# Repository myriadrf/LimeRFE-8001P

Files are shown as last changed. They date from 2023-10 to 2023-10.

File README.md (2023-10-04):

# LimeRFE 8001P

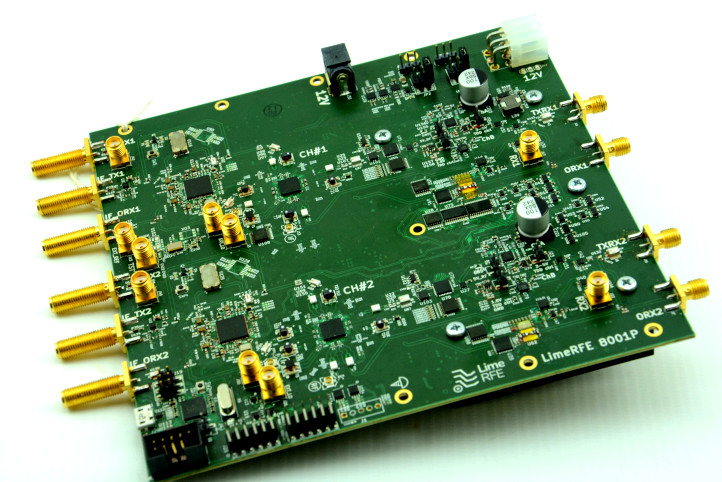
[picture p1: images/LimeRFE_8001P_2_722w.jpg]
LimeRFE 8001P board


## Contents

The LimeRFE 8001P board is a two channel RF front end module capable of frequency
conversion, RF signal amplification and power amplifier linearisation. It can be
configured so that either the integrated driver amplifiers, or external power
amplifiers, are linearised. LimeRFE 8001P is designed with 5G cellular networks
in mind, but may be put to use in other applications with similar requirements.

The directory structure is as follows:

      firmware/<version>/
          LMS8FE                 - Arduino firmware project
      hardware/<version>/
          BOM/                   - Bill of materials
          Gerbers/               - Gerber manufacturing files
          KiCAD/                 - KiCAD design
          PDF/                   - PDF outputs

Note that the firmware should match the hardware version. E.g. use 1v1 firmware
with 1v1 hardware.

## Licensing

The hardware designs are licensed under the Solderpad Hardware License v2.1.

The firmware is licensed under the Apache License, Version 2.0.

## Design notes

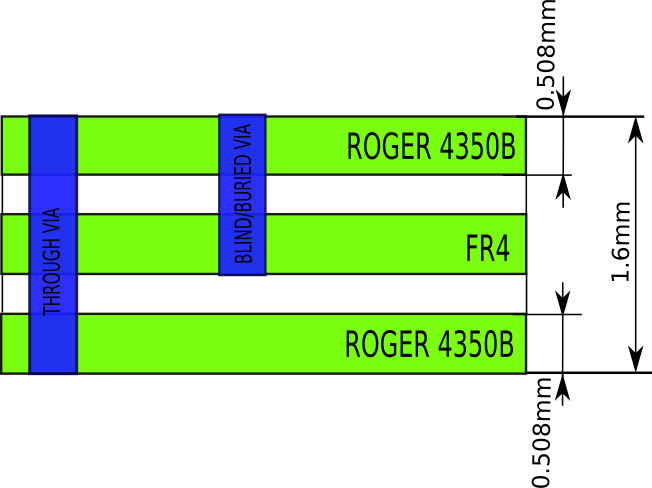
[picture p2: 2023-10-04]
hardware/1v0/Gerbers/STACKUP.png

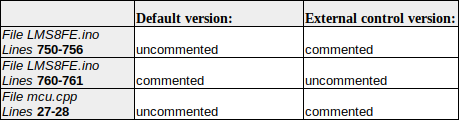
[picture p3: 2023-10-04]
firmware/1v1/TXRX_GUIvsEXTERNAL.png

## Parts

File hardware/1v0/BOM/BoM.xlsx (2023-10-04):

Front_End_5G_1v0
Component | QTY | Reference | Footprint | Supplier | Supplier Part Number | Manufacturer | Manu Part Number | Description | Assemble | Comment | Value
1uF | 48 | C1, C2, C3, C5, C6, C7, C9, C11, C12, C13, C15, C16, C17, C18, C21, C22, C23, C24, C26, C27, C93, C95, C131, C132, C133, C134, C257, C259, C260, C261, C263, C265, C266, C267, C269, C270, C271, C272, C275, C276, C277, C278, C280, C281, C363, C364, C365, C366 | SMD0201 | Digi-Key | 445-8008-1-ND | TDK | C0603X5R0J105M030BC | CAP CER 1UF 6.3V 20% X5R 0201
1nF | 22 | C4, C8, C10, C14, C19, C20, C25, C141, C142, C145, C146, C258, C262, C264, C268, C273, C274, C279, C375, C376, C377, C378 | SMD0201 | Digi-Key | 445-7275-1-ND | TDK Corporation | C0603X7R1E102K030BA | CAP CER 1000PF 25V 10% X7R 0201
10nF | 104 | C28, C29, C30, C31, C32, C34, C37, C40, C42, C48, C50, C83, C91, C92, C98, C167, C169, C179, C180, C181, C182, C183, C184, C189, C205, C223, C224, C225, C226, C229, C230, C231, C235, C242, C246, C251, C252, C253, C254, C255, C256, C284, C285, C287, C288, C289, C290, C296, C307, C321, C322, C323, C324, C325, C326, C327, C329, C330, C387, C388, C389, C390, C391, C392, C393, C396, C458, C459, C466, C467, C468, C525, C526, C575, C576, C577, C578, C579, C580, C581, C583, C584, C585, C586, C587, C588, C589, C590, C591, C592, C593, C594, C595, C596, C597, C598, C599, C600, C601, C603, C605, C630, C631, C634 | SMD0402 | DigiKey | 311-1045-1-ND | Yageo | CC0402ZRY5V7BB103 | CAP_CER_10000PF_16V_Y5V_0402
10uF | 12 | C33, C66, C77, C81, C86, C200, C201, C608, C611, C613, C614, C617 | SMD0603 | Digi-Key | 311-1448-1-ND | Yageo | CC0603MRX5R5BB106 | CAP, CER, 10UF, 6.3V, 20%, X5R, 0603,
NF_10pF | 18 | C35, C399, C400, C403, C404, C405, C409, C410, C518, C519, C531, C532, C534, C537, C538, C539, C573, C574 | SMD0402 | Mouser | 81-GJM1555C1H100GB01 | Murata Electronics | GJM1555C1H100GB01D | Multilayer Ceramic Capacitors MLCC - SMD/SMT 10PF 50V 2% 0402
470pF | 4 | C36, C199, C219, C401 | SMD0402 | Mouser | 81-GRM1555C1H471JA01 | Murata Electronics | GRM1555C1H471JA01D | Multilayer Ceramic Capacitors MLCC - SMD/SMT 0402 470pF 50volts C0G 5%
47nF | 2 | C38, C402 | SMD0402 | Mouser | 81-GCM155R71H473KE2D | Murata Electronics | GCM155R71H473KE02D | Multilayer Ceramic Capacitors MLCC - SMD/SMT 0402 0.047uF 50volts X7R 10%
5pF | 10 | C39, C41, C190, C232, C233, C236, C237, C241, C245, C328 | SMD0402 | Mouser | 80-CBR04C509C5G | KEMET | CBR04C509C5GAC | Multilayer Ceramic Capacitors MLCC - SMD/SMT 50V 5pF C0G 0402 0.25pF
1uF | 30 | C43, C44, C45, C51, C52, C53, C54, C55, C58, C63, C65, C185, C186, C187, C188, C238, C239, C412, C447, C448, C449, C451, C488, C489, C609, C612, C624, C625, C626, C627 | SMD0402 | Digi-Key | 311-1377-1-ND | Yageo | CC0402ZRY5V5BB105 | CAP, CER, 1UF, 6.3V, Y5V, 0402, |  | treba kupiti jos
1nF | 16 | C46, C47, C49, C56, C96, C97, C192, C196, C202, C207, C212, C216, C220, C227, C602, C604 | SMD0402 | DigiKey | 311-1036-1-ND | Yageo | CC0402KRX7R9BB102 | CAP CER 1000PF 50V 10% X7R 0402
10uF | 3 | C57, C78, C206 | SMD1206 | Digi-Key | 311-1376-1-ND | Yageo | CC1206ZKY5V7BB106 | CAP, CER, 10UF, 16V, Y5V, 1206,
1uF | 4 | C59, C82, C610, C616 | SMD0603 | Digi-Key | 490-3897-1-ND | Murata | GRM188R61E105KA12D | CAP_CER_1UF_25V_X5R_0603
4.7uF | 15 | C60, C61, C62, C64, C240, C394, C395, C413, C414, C535, C606, C607, C615, C628, C629 | SMD0402 | DigiKey | 490-5408-1-ND | Murata_Electronics_North_America | GRM155R60J475ME87D | CAP_CER_4.7UF_6.3V_X5R_0402
NF | 22 | C67, C73, C74, C75, C79, C84, C85, C89, C100, C159, C162, C164, C170, C171, C172, C173, C176, C178, C303, C305, C313, C435 | SMD0402 | Mouser | 81-GRM155R71C104KA88 | Murrata Electronic | GRM155R71C104KA88D | SMD/SMT 0402 0.1uF 16volts X7R 10%
1nF | 4 | C68, C163, C166, C174 | SMD0402 | Mouser | 81-GCM155R71H102KA7D | Murrata Electronics | GCM155R71H102KA37D | CAP CER 1000PF 50V 10% X7R 0402
NF_1200pF | 2 | C69, C418 | SMD0402 | Mouser | 81-GRM15R71H122KA01D | Murata_Electronics | GRM155R71H122KA01D | Multilayer_Ceramic_Capacitors_MLCC_-_SMD/SMT_0402_1200pF_50volts_X7R_10%
470nF | 1 | C70 | SMD0402 | Mouser | 81-GRM155R61A474KE5D | Murata_Electronics | GRM155R61A474KE15D | Multilayer_Ceramic_Capacitors_MLCC_-_SMD/SMT
100nF | 2 | C71, C87 | SMD0402 | Mouser | 81-GRM155R71C104KA8J | Murata Electronics | GRM155R71C104KA88J | Multilayer Ceramic Capacitors MLCC - SMD/SMT 0.1uF 16 volts 10%
68nF | 1 | C72 | SMD0402 | Mouser | 81-GRM155R71H683ME4D | Murata_Electronics | GRM155R71H683ME14D | Multilayer_Ceramic_Capacitors_MLCC_-_SMD/SMT
10pF | 1 | C76 | SMD0402 | Farnell | 2332478RL | AVX Corporation | 04023A100JAT2A | CAP, CER, 10PF, 25V, 5%, NPO, 0402,
220pF | 1 | C80 | SMD0402 | DigiKey | 311-1035-2-ND | Yageo | CC0402KRX7R9BB221 | CAP CER, 220PF, 50V, 10%, X7R, 0402,
10uF | 4 | C88, C293, C317, C319 | SMD0603 | Mouser | 81-GRM188R61E106KA3J | Murata Electronics | GRM188R61E106KA73J | Multilayer Ceramic Capacitors MLCC - SMD/SMT
1uF | 1 | C90 | SMD0402 | Mouser | 603-CC402ZRY5V5BB105 | Yageo | CC0402ZRY5V5BB105 | Multilayer Ceramic Capacitors MLCC - SMD/SMT 1.0uF 6.3V Y5V -20/+80%
10pF | 6 | C94, C101, C102, C286, C294, C295 | SMD0201 | Digi-Key | 445-1769-1-ND | TDK Corporation | C0603C0G1H100D030BA | CAP_CER_10PF_50V_C0G_0201
18nF | 1 | C99 | SMD0402 | DigiKey | 311-1706-1-ND | Yageo | CC0402KRX7R7BB183 | CAP_CER_0.018UF_16V_X7R_0402
10pF | 27 | C103, C104, C135, C136, C137, C138, C139, C140, C143, C144, C147, C148, C149, C150, C331, C367, C368, C369, C370, C371, C372, C373, C374, C383, C384, C385, C386 | SMD0201 | Mouser | 81-GJM0335C1E100JB1D | Murata Electronics | GJM0335C1E100JB01D | Multilayer Ceramic Capacitors MLCC - SMD/SMT 10PF 25V 5% 0201
2.3pF | 11 | C105, C106, C119, C120, C123, C124, C332, C333, C334, C347, C348 | SMD0201 | Mouser | 81-GJM0335C1E2R3BB1D | Murata Electronics | GJM0335C1E2R3BB01D | Multilayer Ceramic Capacitors MLCC - SMD/SMT 2.3PF 25V 0.1pf 0201
C_NF | 30 | C107, C108, C109, C110, C111, C112, C115, C116, C128, C130, C151, C153, C154, C157, C158, C335, C337, C338, C339, C340, C356, C357, C358, C359, C360, C361, C362, C380, C381, C382 | SMD0201
0.9pF | 10 | C113, C114, C117, C118, C341, C342, C343, C344, C345, C346 | SMD0201 | Mouser | 81-GJM0335C1ER90BB1D | Murata Electronics | GJM0335C1ER90BB01D | Multilayer Ceramic Capacitors MLCC - SMD/SMT 0.9PF 25V 0.1pf 0201
0.5pF | 10 | C121, C122, C125, C126, C349, C350, C351, C352, C353, C354 | SMD0201 | Mouser | 81-GJM0335C1ER50BB01 | Murata Electronics | GJM0335C1ER50BB01D | Multilayer Ceramic Capacitors MLCC - SMD/SMT 0.5PF 25V 0.1pf 0201
0.6pF | 3 | C127, C129, C355 | SMD0201 | Mouser | 81-GJM0335C1ER60BB1D | Murata Electronics | GJM0335C1ER60BB01D | Multilayer Ceramic Capacitors MLCC - SMD/SMT .6PF 25V .1PF 0201
C_NF | 2 | C152, C336 | SMD0201
1.9nH | 3 | C155, C156, C379 | SMD0201 | Mouser | 81-LQP03TN1N9B02D | Murata Electronics | LQP03TN1N9B02D | Fixed Inductors 1.9 NH +-.1NH
10uF | 1 | C160 | SMD0603_gap04 | Digi-Key | 490-7201-2-ND | Murrata Electronics | GRM188R61C106MA73D | CAP, CER, 10UF, 6.3V, 20%, X5R, 0603,
0.4pF | 2 | C161, C292 | SMD0201 | Digi-Key | 490-8074-1-ND | Murata_Electronics | GJM0335C1ER40WB01D | CAP_CER_0.40PF_25V_NP0_0201
10nF | 4 | C165, C168, C175, C177 | SMD0402 | Mouser | 81-GCM155R71E103KA7D | Murata_Electronics | GCM155R71E103KA37D | Multilayer_Ceramic_Capacitors_MLCC_-_SMD/SMT_0.01uF_25Volts_X7R_10%_
5.6pF | 8 | C191, C194, C198, C210, C211, C214, C218, C283 | SMD0402 | Mouser | 581-04023J5R6BBW | AVX | 04023J5R6BBWTR | Silicon RF Capacitors / Thin Film 25V 5.6pF .1pFTol ThinFilm 0402
10nF | 2 | C193, C213 | SMD0603 | Mouser | 80-C0603C103J5RAC | KEMET | C0603C103J5RAC | Multilayer Ceramic Capacitors MLCC - SMD/SMT 50V 0.01uF 0603 X7R 0.05
1uF | 4 | C195, C197, C215, C217 | SMD0603 | Digi-Key | 490-3897-1-ND | Murata | GRM188R61E105KA12D | CAP_CER_1UF_25V_X5R_0603
100uF | 2 | C203, C221 | EEE-FK1J101P | Mouser | 667-EEE-FK1J101P | Panasonic | EEE-FK1J101P | Aluminium Electrolytic Capacitors - SMD 100UF 63V FK SMD |  | samo 3 komada
4.7uF | 2 | C204, C222 | SMD0603 | DigiKey | - | - | - | CAP_CER_4.7UF_?V_0603
2pF | 2 | C208, C234 | SMD0402 | Mouser | 81-GRM1555C2A2R0CA1D | Murata Electronics | GRM1555C2A2R0CA01D | Multilayer Ceramic Capacitors MLCC - SMD/SMT 0402 2pF 100volts C0G +/-0.25pF
0.6pF | 2 | C209, C282 | SMD0402 | Mouser | 81-GRM1555C2AR60BA1D | Murata Electronics | GRM1555C2AR60BA01D | Multilayer Ceramic Capacitors MLCC - SMD/SMT 0402 0.6pF 100volts C0G +/-0.1pF
1uF | 4 | C228, C320, C632, C633 | SMD0402 | Digi-Key | 311-1377-1-ND | Yageo | CC0402ZRY5V5BB105 | CAP, CER, 1UF, 6.3V, Y5V, 0402,
10pF | 2 | C243, C247 | SMD0402 | Digi-Key | 311-1014-1-ND | Yageo | CC0402JRNPO9BN100 | CAP, CER, 10PF, 50V, 5%, NPO, 0402,
100nF | 15 | C244, C248, C471, C472, C474, C475, C476, C477, C478, C479, C480, C483, C484, C486, C487 | SMD0402 | Mouser | 81-GRM155R71C104KA8J | Murata Electronics | GRM155R71C104KA88J | Multilayer Ceramic Capacitors MLCC - SMD/SMT 0.1uF 16 volts 10%
NF_1000pF | 2 | C249, C250 | SMD0402 | Mouser | 81-GCM155R71H102KA7D | Murata Electronics | GCM155R71H102KA37D | Multilayer Ceramic Capacitors MLCC - SMD/SMT 0402 1000pF 50volts X7R 10%
2.2nF | 1 | C291 | SMD0402 | Mouser | 81-GRM155R71E222KA1D | Murata Electronics | GRM155R71E222KA01D | Multilayer Ceramic Capacitors MLCC - SMD/SMT RECOMMENDED ALT 81-GRM033R71E222KA2D
18pF | 4 | C297, C306, C308, C316 | SMD0402 | Mouser | 81-GRM1555C1H180JA1D | Murata Electronics | GRM1555C1H180JA01D | Multilayer Ceramic Capacitors MLCC - SMD/SMT RECOMMENDED ALT 81-GRM0335C1H180JA1D
100pF | 8 | C298, C300, C301, C304, C309, C311, C312, C315 | SMD0402 | Mouser | 81-GRM1555C1H101JA1D | Murata Electronics | GRM1555C1H101JA01D | Multilayer Ceramic Capacitors MLCC - SMD/SMT 0402 100pF 50volts C0G 5%
1uF | 8 | C299, C302, C310, C314, C462, C481, C482, C620 | SMD0402 | Mouser | 603-CC402ZRY5V5BB105 | Yageo | CC0402ZRY5V5BB105 | Multilayer Ceramic Capacitors MLCC - SMD/SMT 1.0uF 6.3V Y5V -20/+80%
47uF | 1 | C318 | SMD2220 | Mouser | CGA9N3X7R1E476M230KB | Murata Electronics | GRM155R61H474KE11D | Multilayer Ceramic Capacitors MLCC - SMD/SMT .47UF 50V 10% 0402
1nF | 34 | C397, C398, C492, C495, C496, C497, C498, C499, C500, C501, C502, C503, C504, C505, C506, C508, C509, C527, C529, C543, C546, C547, C548, C549, C550, C551, C552, C554, C555, C556, C557, C560, C562, C563 | SMD0402 | Mouser | 81-GRM1555C1H102JA1D | Murata | GRM1555C1H102JA01D | Multilayer Ceramic Capacitors MLCC - SMD/SMT 1000PF 50V 5% 0402
NF_1uF | 2 | C406, C528 | SMD0603 | Mouser | 81-GRM39R105K10 | Murata | GRM188R61A105KA61D | Multilayer Ceramic Capacitors MLCC - SMD/SMT PLEASE SEE MURATA'S SUGGESTED ALTERNATE GRM033R61A105ME15D
NF_2.2uF | 2 | C407, C530 | SMD0603 | Mouser | 81-GRM188R71A225KE5J | Murata | GRM188R71A225KE15J | Multilayer Ceramic Capacitors MLCC - SMD/SMT 2.2UF 10V 10% 0603
NF_1nF | 6 | C408, C411, C524, C533, C536, C582 | SMD0402 | Mouser | 81-GRM1555C1H102JA1D | Murata | GRM1555C1H102JA01D | Multilayer Ceramic Capacitors MLCC - SMD/SMT 1000PF 50V 5% 0402
NF_100nF | 14 | C415, C422, C423, C426, C427, C428, C430, C432, C433, C438, C440, C442, C445, C446 | SMD0402 | DigiKey | 311-1047-1-ND | Yageo | CC0402ZRY5V7BB104 | CAP, CER, 0.1UF, 16V, Y5V, 0402,
NF_10nF | 4 | C416, C425, C441, C444 | SMD0402 | DigiKey | 311-1045-1-ND | Yageo | CC0402ZRY5V7BB103 | CAP_CER_10000PF_16V_Y5V_0402
NF_1nF | 4 | C417, C424, C439, C443 | SMD0402 | DigiKey | 311-1036-1-ND | Yageo | CC0402KRX7R9BB102 | CAP CER 1000PF 50V 10% X7R 0402
NF_470nF | 1 | C419 | SMD0402 | Mouser | 81-GRM155R61A474KE5D | Murata_Electronics | GRM155R61A474KE15D | Multilayer_Ceramic_Capacitors_MLCC_-_SMD/SMT
NF_18nF | 1 | C420 | SMD0402 | DigiKey | 311-1706-1-ND | Yageo | CC0402KRX7R7BB183 | CAP_CER_0.018UF_16V_X7R_0402
NF_68nF | 1 | C421 | SMD0402 | Mouser | 81-GRM155R71H683ME4D | Murata_Electronics | GRM155R71H683ME14D | Multilayer_Ceramic_Capacitors_MLCC_-_SMD/SMT
NF_10pF | 1 | C429 | SMD0402 | Digi-Key | 311-1014-1-ND | Yageo | CC0402JRNPO9BN100 | CAP, CER, 10PF, 50V, 5%, NPO, 0402,
NF_220pF | 1 | C431 | SMD0402 | DigiKey | 311-1035-1-ND | Yageo | CC0402KRX7R9BB221 | CAP CER, 220PF, 50V, 10%, X7R, 0402,
NF_10uF | 2 | C434, C437 | SMD0603_v2 | Digi-Key | 311-1448-1-ND | Yageo | CC0603MRX5R5BB106 | CAP, CER, 10UF, 6.3V, 20%, X5R, 0603,
NF_10uF | 1 | C436 | SMD0603_gap04 | Digi-Key | 311-1448-1-ND | Yageo | CC0603MRX5R5BB106 | CAP, CER, 10UF, 6.3V, 20%, X5R, 0603,
15pF | 6 | C450, C490, C512, C540, C541, C567 | SMD0402 | Mouser | 81-GJM1555C1H150JB1D | Murata Electronics | GJM1555C1H150JB01D | Multilayer Ceramic Capacitors MLCC - SMD/SMT 0402 15pF 50Volts C0G 5%
1nF | 2 | C452, C455 | SMD0603 | Mouser | 581-06035C102K | AVX | 06035C102KAT2A | Multilayer Ceramic Capacitors MLCC - SMD/SMT 50V 1nF X7R 0603 10%TOL
NF_100nF | 2 | C453, C456 | SMD0603 | Mouser | 80-C0603C104M5R | KEMET | C0603C104M5RACTU | Multilayer Ceramic Capacitors MLCC - SMD/SMT 50V 0.1uF 0603 X7R 20%
1000pF | 4 | C454, C457, C463, C621 | SMD0402 | Mouser | 81-GCM155R71H102KA7D | Murata Electronics | GCM155R71H102KA37D | Multilayer Ceramic Capacitors MLCC - SMD/SMT 0402 1000pF 50volts X7R 10%
100pF | 6 | C460, C461, C464, C618, C619, C622 | SMD0402 | Mouser | 667-ECJ-0EC1H101J | Murata Electronics | ECJ-0EC1H101J | Multilayer Ceramic Capacitors MLCC - SMD/SMT 100PF 50V 5% 0402
27pF | 4 | C465, C469, C470, C623 | SMD0402 | Mouser | 81-GCM1555C1H270FA6D | Murata Electronics | GCM1555C1H270FA16D | Multilayer Ceramic Capacitors MLCC - SMD/SMT 0402 27pF 50volts C0G 1%
3.9nF | 1 | C473 | SMD0402 | Mouser | 581-04025C392JAT2A | AVX | 04025C392JAT2A | Multilayer Ceramic Capacitors MLCC - SMD/SMT 50V 3900pF X7R 0402 5%
10uF | 1 | C485 | SMD0603 | Mouser | 81-GRM188R61E106KA3J | Murata Electronics | GRM188R61E106KA73J | Multilayer Ceramic Capacitors MLCC - SMD/SMT
0.2pF | 2 | C491, C542 | SMD0402 | Mouser | 81-GJM1555C1HR20BB01 | Murata Electronics | GJM1555C1HR20BB01D | Multilayer Ceramic Capacitors MLCC - SMD/SMT .2PF 50V .1PF 0402
0.9pF | 2 | C493, C544 | SMD0402 | Mouser | 81-GJM1555C1HR90BB1D | Murata Electronics | GJM1555C1HR90BB01D | Multilayer Ceramic Capacitors MLCC - SMD/SMT .9PF 50V .1PF 0402
2.2uF | 6 | C494, C510, C513, C545, C564, C568 | SMD0603 | Mouser | 81-GRM188R71A225KE5J | Murata | GRM188R71A225KE15J | Multilayer Ceramic Capacitors MLCC - SMD/SMT 2.2UF 10V 10% 0603
0.5pF | 2 | C507, C561 | SMD0402 | Mouser | 81-GJM1555C1HR50BB01 | Murata Electronics | GJM1555C1HR50BB01D | Multilayer Ceramic Capacitors MLCC - SMD/SMT .5PF 50V .1PF 0402
NF_47nF | 6 | C511, C514, C515, C553, C558, C559 | SMD0402 | Mouser | 81-GCM155R71H473KE2D | Murata Electronics | GCM155R71H473KE02D | Multilayer Ceramic Capacitors MLCC - SMD/SMT 0402 0.047uF 50volts X7R 10%
10pF | 4 | C516, C517, C571, C572 | SMD0402 | Mouser | 81-GJM1555C1H100GB01 | Murata Electronics | GJM1555C1H100GB01D | Multilayer Ceramic Capacitors MLCC - SMD/SMT 10PF 50V 2% 0402
NF_100nF | 4 | C520, C521, C565, C566 | SMD0402 | Mouser | 81-GRM155R71C104KA8J | Murata Electronics | GRM155R71C104KA88J | Multilayer Ceramic Capacitors MLCC - SMD/SMT 0.1uF 16 volts 10%
NF_100pF | 4 | C522, C523, C569, C570 | SMD0402 | Mouser | 81-GRM1555C1H101JA1D | Murata Electronics | GRM1555C1H101JA01D | Multilayer Ceramic Capacitors MLCC - SMD/SMT 0402 100pF 50volts C0G 5%
47346-0001 | 1 | CON1 | USB-MINI-B | Mouser | 538-47346-0001 | Manufacturer | 47346-0001 | MICRO USB B RECPT BTTM MOUNT ASSY
SML-D12M1WT86 | 4 | D1, D2, D3, D4 | LED_0603 | Mouser | 755-SML-D12M1WT86 | Rohm Semiconductor | SML-D12M1WT86 | LED YLW/GREEN 2.2V DIFFUSED 0603 SMD
600 Ohm @100MHz | 38 | FB1, FB2, FB3, FB4, FB5, FB6, FB7, FB8, FB9, FB10, FB11, FB12, FB13, FB14, FB15, FB25, FB26, FB27, FB28, FB31, FB32, FB33, FB34, FB35, FB36, FB37, FB38, FB39, FB40, FB41, FB42, FB43, FB44, FB45, FB48, FB49, FB50, FB51 | SMD0201 | Digi-Key | 587-3277-1-ND | Taiyo Yuden | BK0603TS601-T | FERRITE BEAD 600 OHM 0201
600_Ohm_@_100MHz_2A | 1 | FB16 | SMD0805 | Mouser | 810-MPZ2012S601AT000 | TDK | MPZ2012S601AT000 | Ferrite Beads 600ohms 2A 100mOhms 0805 Ferrite Chip
60 Ohm @100MHz, 1A | 15 | FB17, FB18, FB19, FB20, FB21, FB23, FB24, FB30, FB46, FB53, FB54, FB55, FB56, FB57, FB58 | SMD0805 | Digi-Key | 445-2204-1-ND | TDK Corporation | MMZ2012Y600B | FERRITE CHIP, BEAD, 60 OHM, SMD,
600 Ohm @ 100MHz, 0.3A | 1 | FB22 | SMD0402 | Digi-Key | 445-2162-1-ND | TDK Corporation | MMZ1005S601C | FERRITE CHIP BEAD, 600 OHM, SMD,
600_Ohm_@_100MHz_500mA | 1 | FB29 | SMD0603_gap04 | Digi-Key | 490-3994-2-ND | Murata_Electronics | BLM18EG601SN1D | FERRITE_BEAD_600_OHM_0603_1LN_
NF_600 Ohm @ 100MHz, 0.3A | 1 | FB47 | SMD0402 | Digi-Key | 445-2162-1-ND | TDK Corporation | MMZ1005S601C | FERRITE CHIP BEAD, 600 OHM, SMD,
NF_600_Ohm_@_100MHz_500mA | 1 | FB52 | SMD0603_gap04 | Digi-Key | 490-3994-2-ND | Murata_Electronics | BLM18EG601SN1D | FERRITE_BEAD_600_OHM_0603_1LN_
AD5513 | 2 | IC1, IC2 | AD5513 | Mouser | 584-ADL5513ACPZ-R7 | Analog Devices | ADL5513ACPZ-R7 | RF Detector 1MHz-4GHz 80 dB
732511352 | 2 | J1, J29 | SMA_vert_SMD | Digi-Key | WM9458-ND | Molex Inc | 732511352 | SMA JACK 50 OHM VERT SMD
68000-103HLF | 3 | J2, J24, J27 | pin_header_1x3 | Digi-Key | 609-3461-ND | FCI | 68000-103HLF | BERGSTIK II .100" SR STRAIGHT
732511352 | 6 | J3, J13, J14, J17, J22, J26 | SMA_vert_SMD | Digi-Key | WM9458-ND | Molex Inc | 732511352 | SMA JACK 50 OHM VERT SMD
SMA_H_142-0701-851 | 10 | J4, J5, J6, J7, J8, J9, J10, J11, J15, J20 | SMA_H | Mouser | 530-142-0701-851 | Johnson / Cinch Connectivity Solutions | 142-0701-851 | RF Connectors / Coaxial Connectors PC END MT JCK GLD .062 BOARDS TAB
Jumper_SNM-100-BK-T | 5 | J12, J25, J47, J54, J56 | SNM-100-BK-T | Mouser | 200-SNM100BKT | Samtec | SNM-100-BK-T | Headers & Wire Housings .050" x .100" Shunt
CONN_HEADER_TSM-102-04-T-SV | 9 | J16, J18, J21, J23, J37, J40, J46, J53, J55 | TSM-102-04-T-SV | Mouser | TSM-102-04-T-SV | Samtec | 200-TSM10204TSV | Headers & Wire Housings .100" Surface Mount Terminal Strip
CONN_HEADER_TSM-103-04-F-DV | 1 | J19 | TSM-103-04-F-DV | Mouser | 200-TSM10304FDV | Samtec | TSM-103-04-F-DV | Headers & Wire Housings .100" Surface Mount Terminal Strip
PMOD_CONN | 6 | J28, J30, J31, J36, J51, J52 | PMOD_CONN | Mouser | 649-95278-401-06LF | Amphenol FCI | 95278-401-06LF | Headers & Wire Housings BERGSTIK SMT
10056844-114LF | 2 | J32, J48 | 10056844-114LF | Mouser |  | HARTING |  | Headers & Wire Housings 14 POS VERTICAL THROUGH MNT
NF_UMC_SMD | 2 | J33, J34 | UMC_SMD | Digi-Key | WM5587CT-ND | Molex_LLC | 734120110 | CONN_UMC_RCPT_STR_50_OHM_SMD
UMC_SMD | 2 | J35, J57 | UMC_SMD | Digi-Key | WM5587CT-ND | Molex_LLC | 734120110 | CONN_UMC_RCPT_STR_50_OHM_SMD
732511352 | 4 | J42, J43, J49, J50 | SMA_vert_SMD | Digi-Key | WM9458-ND | Molex Inc | 732511352 | SMA JACK 50 OHM VERT SMD
CONN_HEADER_1744037-2 | 1 | J44 | 1744037-2 | Digikey | TSM-102-04-T-SV | TE Connectivity AMP Connectors | A112698-ND | Connector Header Through Hole 2 position 0.200" (5.08mm)
PIN_HEADER_2X3_0353180620 | 1 | J45 | 353180620 | Digikey | WM13196-ND | Molex | 353180620 | Connector Header Through Hole, Right Angle 6 position 0.165" (4.20mm)
15912060 | 2 | JP1, JP2 | PINHEADER_2X3 | Digi-Key | WM17449-ND | Molex Inc | 15912060 | CONN HEADER 6POS .100" VERT TIN
 | 3 | L1, L3, L27 | SMD0201
1.6nH | 5 | L2, L4, L28, L29, L30 | SMD0201 | Mouser | 81-LQP03TN1N6B02D | Murata | LQP03TN1N6B02D | Fixed Inductors 56nH 5% Hi-Freq
8.2nH | 4 | L5, L7, L9, L11 | IND_0402 | Mouser | 81-LQW15AN8N2G00D | Murata | LQW15AN8N2G00D | Fixed Inductors 8.2 NH 2%
3.6nH | 10 | L6, L8, L10, L12, L32, L33, L34, L36, L37, L38 | IND_0402 | Mouser | 81-LQW15AN3N6C10D | Murata | LQW15AN3N6C10D | Fixed Inductors 3.6 NH 2%
1.2nH | 2 | L13, L18 | SMD0402 | Mouser | 994-0402CS-1N2XJLU | Coilcraft | 0402CS-1N2XJLU | Fixed Inductors 1005 1.2nH Unshld 5% 740mA 90mOhms AECQ2
10nH | 4 | L14, L16, L19, L21 | SMD0603 | Mouser | 994-0603HP-10NXGLW | Coilcraft | 0603HP-10NXGLW | Fixed Inductors 0603HP Hi Perfrmnce 10 nH 2 % 1.4 A
2.4nH | 2 | L15, L20 | SMD0402 | Mouser | 994-0402CS-2N4XGLU | Coilcraft | 0402CS-2N4XGLU | Fixed Inductors 1005 2.4nH Unshld 2% 790mA 68mOhms AECQ2
3.3nH | 2 | L17, L22 | SMD0603 | Mouser | 994-0603HP-3N3XJLW | Coilcraft | 0603HP-3N3XJLW | Fixed Inductors 0603 3.3nH Unshld 5% 1.9A 24mOhms
47nH | 2 | L23, L25 | SMD0402 | Mouser | 81-LQW04AN47NH20D | Murata | LQW04AN47NH20D | Fixed Inductors Fixed IND 47nH 140mA NONAUTO
56nH | 2 | L24, L26 | SMD0402 | Mouser | 81-LQW15AW56NJ80D | Murata | LQW15AW56NJ80D | Fixed Inductors Fixed IND 56nH 480mA NONAUTO
8.2nH | 2 | L31, L35 | IND_0402 | Coilcraft | 0402HP-8N2XJLU | Coilcraft | 0402HP-8N2XJLU | Inductor, 8.2 nH, 0402, 5%,
2.2uH | 1 | L39 | SPM6530T-2R2M | Mouser | 810-SPM6530T-2R2M | TDK Corporation | SPM6530T-2R2M | Fixed Inductors 2.2uH 0.0173ohms 7.1x6.5x3mm
12nH | 2 | L40, L41 | SMD0402 | Mouser | 994-0402CS-12NXJLW | COILCRAFT | 0402CS-12NXJLW | Fixed Inductors 0402CS AEC-Q200 12 nH 5 % 0.64 A
470R | 2 | L42, L65 | SMD0402 | Mouser | 81-BLM15BD471SN1D | Murata | BLM15BD471SN1D | Ferrite Beads 470 OHM 25%
470R | 1 | L43 | SMD0603 | Mouser | 81-BLM18PG471SN1D | Murata | BLM18PG471SN1D | Ferrite Beads 470 OHM 25%
5.6nH | 4 | L44, L45, L66, L67 | SMD0402 | Digikey | 587-1513-2-ND | Taiyo Yuden | HK10055N6S-T | FIXED IND 5.6NH 430MA 230MOHM SM
18nH | 2 | L46, L68 | SMD0402 | Digikey | 587-1522-6-ND | Taiyo Yuden | HK100518NJ-T | 18 nH Unshielded Multilayer Inductor 310 mA 550mOhm Max 0402 (1005 Metric)
68nH | 2 | L47, L48 | SMD0603 | Mouser | 994-0603CS-68NXJLW | Coilcraft | 0603CS-68NXJLW | Fixed Inductors 0603HP Hi Perfrmnce 100 nH 5 % 0.47 A
1.2nH | 4 | L57, L58, L69, L70 | SMD0402 | DigiKey | 587-1499-6-ND | Taiyo Yuden | HK10051N2S-T | 1.2 nH Unshielded Multilayer Inductor 300 mA 90mOhm Max 0402 (1005 Metric)
3.3nH | 2 | L59, L71 | SMD0402 | Digikey | 587-1507-6-ND | Taiyo Yuden | HK10053N3S-T | 3.3 nH Unshielded Multilayer Inductor 550 mA 160mOhm Max 0402 (1005 Metric)
8.2nH | 2 | L60, L72 | SMD0402 | DigiKey | 587-1517-6-ND | Taiyo Yuden | HK10058N2J-T | 8.2 nH Unshielded Multilayer Inductor 380 mA 280mOhm Max 0402 (1005 Metric)
2.2nH | 4 | L61, L62, L73, L74 | SMD0402 | DigiKey | 587-1503-6-ND | Taiyo Yuden | HK10052N2S-T | 2.2 nH Unshielded Multilayer Inductor 700 mA 130mOhm Max 0402 (1005 Metric)
120R | 4 | L63, L64, L75, L76 | SMD0603 | Mouser | 81-BLM11A121S | Murata | BLM18AG121SN1D | Ferrite Beads 120 OHM 25%
Green | 5 | LD1, LD2, LD4, LD5, LD6 | LED_0603 | Digi-Key | 475-1409-1-ND | OSRAM Opto Semiconductors Inc | LG Q971-KN-1 | LED, CHIPLED, 570NM, GREEN, 0603, SMD,
NF_MMBT3904 | 2 | Q1, Q3 | MMBT3904 | Mouser | 637-MMBT3904 | Diotec Semiconductor | MMBT3904 | Bipolar Transistors - BJT Bipolar Transistor, SOT-23, 40V, 200mA, NPN
2N7002-G | 2 | Q2, Q4 | SOT-23 | Mouser | 2N7002-G | onsemi / Fairchild | 2N7002-G | MOSFET N-CHANNEL 60V 115mA
0R | 6 | R1, R91, R92, R130, R160, R161 | SMD0201 | Digi-Key | RHM0.0CCCT-ND | Rohm Semiconductor | MCR006YRTJ000 | RES 0.0 OHM 1/20W JUMP 0201 SMD
10K | 47 | R2, R41, R70, R106, R111, R118, R120, R131, R133, R134, R135, R136, R137, R140, R141, R142, R144, R149, R153, R207, R208, R209, R211, R251, R252, R253, R255, R283, R284, R285, R286, R295, R297, R298, R299, R517, R518, R519, R520, R521, R522, R523, R524, R525, R526, R558, R576 | SMD0402 | Digi-Key | RMCF0402FT10K0CT-ND | Stackpole Electronics Inc | RMCF0402FT10K0 | RES 10K OHM 1/16W 1% 0402
NF_10K | 39 | R3, R4, R221, R349, R350, R351, R352, R353, R354, R355, R356, R357, R358, R359, R360, R375, R379, R380, R381, R397, R399, R418, R419, R420, R421, R422, R423, R431, R436, R437, R438, R439, R440, R441, R442, R449, R451, R487, R500 | SMD0402 | Digi-Key | - | - | - | -
49.9R | 10 | R5, R99, R190, R361, R362, R417, R537, R573, R574, R575 | SMD0402 | Mouser | 667-ERJ-U02F49R9X | Panasonic | ERJ-U02F49R9X | Thick Film Resistors - SMD 0402 1% 49.9ohm Anti-Sulfur AEC-Q200
NF_0R | 12 | R6, R7, R8, R9, R10, R11, R12, R13, R16, R17, R18, R19 | SMD0603 | Digi-Key | 541-2779-1-ND | Vishay_Dale | RCS06030000Z0EA | RES SMD 0 OHM JUMPER 1/4W 0603
20K | 16 | R14, R15, R20, R21, R57, R58, R60, R61, R71, R84, R143, R148, R407, R408, R490, R553 | SMD0402 | Mouser | 71-CRCW040220K0FKEDC | Vishay | CRCW040220K0FKEDC | Thick Film Resistors - SMD 1/16watt 20Kohms 1% Commercial Use
0R | 86 | R22, R23, R38, R40, R48, R73, R75, R80, R104, R105, R108, R127, R189, R198, R199, R210, R215, R216, R222, R223, R224, R225, R228, R235, R236, R261, R262, R265, R267, R268, R271, R290, R293, R294, R304, R305, R367, R368, R369, R370, R371, R372, R376, R377, R378, R383, R384, R385, R386, R389, R391, R394, R402, R403, R414, R424, R432, R433, R434, R435, R443, R447, R448, R450, R453, R454, R455, R456, R459, R494, R497, R501, R502, R535, R536, R544, R557, R561, R563, R565, R569, R572, R581, R582, R584, R585 | SMD0402 | Digi-Key | 311-0.0JRCT-ND | Yageo | RC0402JR-070RL | RES, 0.0 OHM,1/16W, JUMP, 0402 SMD,
NF_0R | 4 | R24, R195, R197, R200 | SMD0603 | Mouser | RCS06030000Z0EA | Vishay_Dale | RCS06030000Z0EA | Thick Film Resistors - SMD 0.25watt ZeroOhms
0R | 15 | R25, R26, R90, R94, R95, R96, R97, R155, R173, R183, R184, R185, R186, R196, R296 | SMD0201 | Digi-Key | RHM0.0CCCT-ND | Rohm Semiconductor | MCR006YRTJ000 | RES 0.0 OHM 1/20W JUMP 0201 SMD
110K | 6 | R27, R31, R56, R72, R101, R241 | SMD0402 | Digi-Key | 311-110KJRCT-ND | Yageo | RC0402JR-07110KL | RES_SMD_110K_OHM_5%_1/16W_0402
34K8 | 14 | R28, R30, R32, R34, R36, R44, R242, R246, R259, R291, R344, R346, R410, R567 | SMD0402 | Digi-Key | YAG3125CT-ND | Yageo | RC0402FR-0734K8L | RES_SMD_34.8K_OHM_1%_1/16W_0402
19K6 | 2 | R29, R566 | SMD0402 | Digi-Key | YAG3026CT-ND | Yageo | RC0402FR-0719K6L | RES_SMD_19.6K_OHM_1%_1/16W_0402
23K2 | 2 | R33, R254 | SMD0402 | Digi-Key | YAG3066CT-ND | Yageo | RC0402FR-0723K2L | RES_SMD_23.2K_OHM_1%_1/16W_0402
44K2 | 5 | R35, R43, R243, R292, R345 | SMD0402 | Digi-Key | YAG3163CT-ND | Yageo | RC0402FR-0744K2L | RES_SMD_44.2K_OHM_1%_1/16W_0402
0R | 67 | R37, R39, R42, R46, R47, R49, R50, R52, R53, R54, R59, R62, R64, R103, R107, R109, R110, R115, R116, R126, R128, R171, R193, R194, R201, R206, R260, R263, R264, R266, R269, R270, R282, R287, R288, R289, R302, R303, R306, R307, R318, R319, R342, R343, R347, R348, R365, R404, R409, R411, R412, R415, R425, R428, R534, R545, R556, R560, R562, R568, R571, R577, R578, R579, R580, R583, R595 | SMD0402 | Digi-Key | 311-0.0JRCT-ND | Yageo | RC0402JR-070RL | RES, 0.0 OHM,1/16W, JUMP, 0402 SMD,
4K99 | 2 | R45, R559 | SMD0402 | Digi-Key | 311-4.99KLRCT-ND | Yageo | RC0402FR-074K99L | RES_SMD_4.99K_OHM_1%_1/16W_0402
680R | 3 | R51, R55, R83 | SMD0402 | Digi-Key | 311-680LRCT-ND | Yageo | RC0402FR-07680RL | RES, 680 OHM, 1/16W, 1%, 0402, SMD,
0R | 1 | R63 | SMD0402 | Mouser | 603-RC0402FR-0769K8L | Yageo | RC0402FR-0769K8L | Thick_Film_Resistors_-_SMD_Thick_Film_Resistors
5K1 | 2 | R65, R312 | SMD0402 | Mouser | 603-RC0402FR-075K1L | Yageo | RC0402FR-075K1L | Thick_Film_Resistors_-_SMD_4.1K_OHM_1%
10R | 1 | R66 | SMD0402 | Digi-Key | 311-10JRCT-ND | Yageo | RC0402JR-0710RL | RES, 10 OHM, 1/16W, 5%, 0402, SMD,
470R | 1 | R67 | SMD0402 | Digi-Key | P470DECT-ND | Panasonic Electronic Components | ERA-2AED471X | RES, 470 OHM, 1/16W, .5%, 0402 SMD,
NF_49.9R | 2 | R68, R570 | SMD0402 | Mouser | 667-ERJ-U02F49R9X | Panasonic | ERJ-U02F49R9X | Thick Film Resistors - SMD 0402 1% 49.9ohm Anti-Sulfur AEC-Q200
1k | 1 | R69 | SMD0402 | Digi-Key | RMCF0402FT1K00CT-ND | Stackpole Electronics Inc | RMCF0402FT1K00 | RES 1K OHM 1/16W 1% 0402
51R | 2 | R74, R79 | SMD0402 | Digi-Key | 71-CRCW040251R0FKED | Vishay Dale | CRCW040251R0FKED | RES, 51 OHM, 1/16W, 5%, 0402, SMD,
47R | 3 | R76, R77, R78 | SMD0402 | Digi-Key | 311-47.0LRCT-ND | Yageo | RC0402FR-0747RL | RES, 47 OHM, 1/16W, 1%, 0402, SMD,
27R | 4 | R81, R88, R308, R309 | SMD0402 | Mouser | 667-ERJ-2RKD27R0X | Panasonic | ERJ2RKD27R0X | Thick Film Resistors - SMD 0402 Resistor 0.5% 100ppm 27Ohm
1.2K | 2 | R82, R89 | SMD0402 | Mouser | 603-AC0402JR-071K2L | Yageo | AC0402JR-071K2L | Thick Film Resistors - SMD 1/16W 1.2K ohm 5% AEC-Q200
0R | 108 | R85, R100, R129, R132, R163, R164, R165, R166, R167, R168, R169, R170, R174, R175, R176, R179, R180, R181, R182, R187, R188, R202, R203, R204, R322, R323, R324, R325, R326, R327, R328, R329, R330, R331, R332, R333, R334, R335, R336, R337, R338, R339, R340, R341, R405, R406, R413, R416, R460, R461, R462, R463, R464, R465, R466, R467, R468, R469, R470, R471, R475, R476, R477, R478, R479, R480, R481, R482, R483, R484, R485, R486, R504, R505, R506, R507, R508, R509, R510, R511, R512, R513, R514, R515, R516, R527, R528, R529, R530, R531, R538, R539, R540, R541, R542, R547, R548, R549, R550, R551, R586, R587, R588, R589, R590, R591, R592, R593 | SMD0201 | Digi-Key | - | - | - | RES_0.0_OHM_0402_SMD
390R | 2 | R86, R138 | SMD0402 | Mouser | 603-RC0402JR-07390RL | Yageo | RC0402JR-07390RL | Thick Film Resistors - SMD 390 OHM 5%
NF | 6 | R87, R139, R191, R192, R205, R594 | SMD0402 | Digi-Key | - | - | - | RES_0.0_OHM_0402_SMD
0R | 4 | R93, R98, R532, R533 | SMD0805 | Digi-Key | 311-0.0ARCT-ND | Yageo | RC0805JR-070RL | RES 0.0 OHM 1/4W JUMP 0805 SMD
40K | 1 | R102 | SMD0402 | Mouser | 667-ERJ-U02F4022X | Panasonic | ERJ-U02F4022X | RES_SMD_34.8K_OHM_1%_1/16W_0402
33R2 | 1 | R112 | SMD0402 | Digi-Key | 311-33.2LRCT-ND | Yageo | RC0402FR-0733R2L | RES_SMD_33.2_OHM_1%_1/16W_0402
49R9 | 3 | R113, R124, R172 | SMD0402 | Digi-Key | 311-49.9LRCT-ND | Yageo | RC0402FR-0749R9L | RES_SMD_49.9_OHM_1%_1/16W_0402
4K99_NF | 3 | R114, R233, R234 | SMD0402 | Digi-Key | 311-4.99KLRCT-ND | Yageo | RC0402FR-074K99L | RES_SMD_4.99K_OHM_1%_1/16W_0402
3.92K | 2 | R117, R125 | SMD0402 | Mouser | 71-CRCW04023K92FKEDC | Vishay Dale | CRCW04023K92FKEDC | Thick Film Resistors - SMD 1/16W 3.92Kohms 1% Commercial Use
39R | 3 | R119, R121, R122 | SMD0402 | Digi-Key | 311-39.0LRCT-ND | Yageo | RC0402FR-0739RL | RES_SMD_39_OHM_1%_1/16W_0402
49R9_NF | 2 | R123, R240 | SMD0402 | Digi-Key | 311-49.9LRCT-ND | Yageo | RC0402FR-0749R9L | RES_SMD_49.9_OHM_1%_1/16W_0402
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

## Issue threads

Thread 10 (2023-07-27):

Enable software control of driver linearisation.

9600, 2023-07-27:
Implement changes to enable software control of linearising the board's own drivers vs. an external PA, so that it is no longer necessary to rework the board to change configuration.

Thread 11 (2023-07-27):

Enable software control of TDD/FDD configuration.

9600, 2023-07-27:
Implement updates to enable configuration of TDD vs. FDD (combined TX/RX or split), so that it is no longer necessary to rework the board to change this configuration.

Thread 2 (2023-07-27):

Swap vertical launch SMA connectors for UFL.

9600, 2023-07-27:
There are already some UFL connectors on this side of the board and not sure why SMA was chosen for other RF connectors.

This will make it possible to fit the board into a 1U enclosure.

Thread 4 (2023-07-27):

Change 6-pin DC power connector to 2-pin Molex Micro-Fit.

9600, 2023-07-27:
A 2-pin Micro-Fit connector should handle the required current.

Presumably the 6-pin connector is PCIe standard? Which would not be of use, since the board will not be fitted into a PC enclosure.

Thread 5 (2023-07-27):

Change headers to Molex Pico-Blade.

9600, 2023-07-27:
Change the following connectors to Pico-Blade:

- J36
- J28
- USB box header

It was originally requested that the USB header for system integration follow the PC motherboard standard, but this doesn't give us much benefit.

Swapping connectors will reduce the height of stand-offs required when fitting the board into an enclosure, in turn allowing the board to be housed in a 1U enclosure instead of 2U. Also captive connector types should be used.

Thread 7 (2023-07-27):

Review other headers and swap connector type where appropriate.

9600, 2023-07-27:
E.g. J19, J2, J24.

Where a header may need to be used as part of system integration, it should be changed to a captive type and ideally edge launch, e.g. PicoBlade. If a header is for test purposes only and would never be used in production, it's fine to just leave it as a pin header.

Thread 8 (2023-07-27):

Review heat sink part.

9600, 2023-07-27:
It feels as though a single smaller, or alternatively perhaps two smaller yet, heat sink should suffice given the board TDP.

A drop in replacement has been found which, together with connector changes, would allow the board to be integrated into a 1U enclosure, rather than it having to be 2U and hence twice the size.

https://www.mouser.co.uk/ProductDetail/Wakefield-Vette/559-50AB

At worst case suggest using this part, assuming that suitable performance can be verified.

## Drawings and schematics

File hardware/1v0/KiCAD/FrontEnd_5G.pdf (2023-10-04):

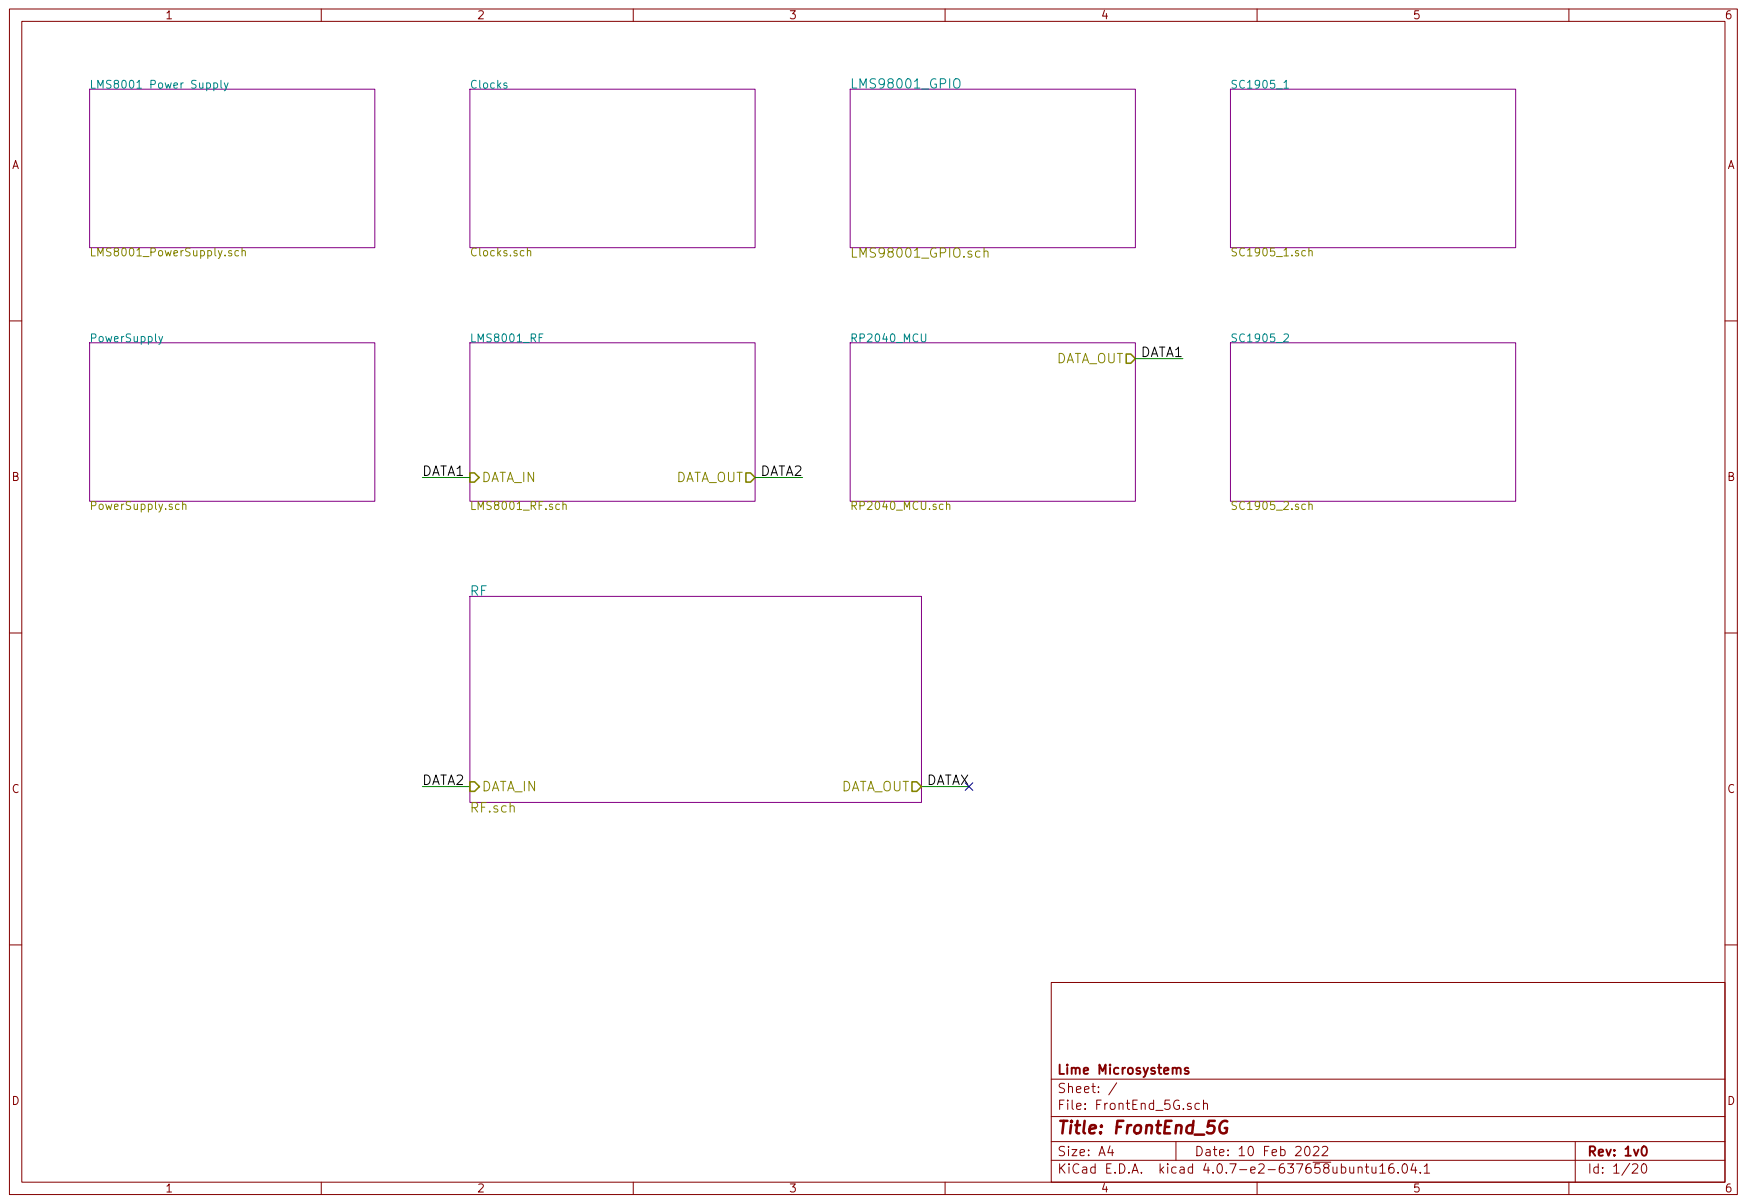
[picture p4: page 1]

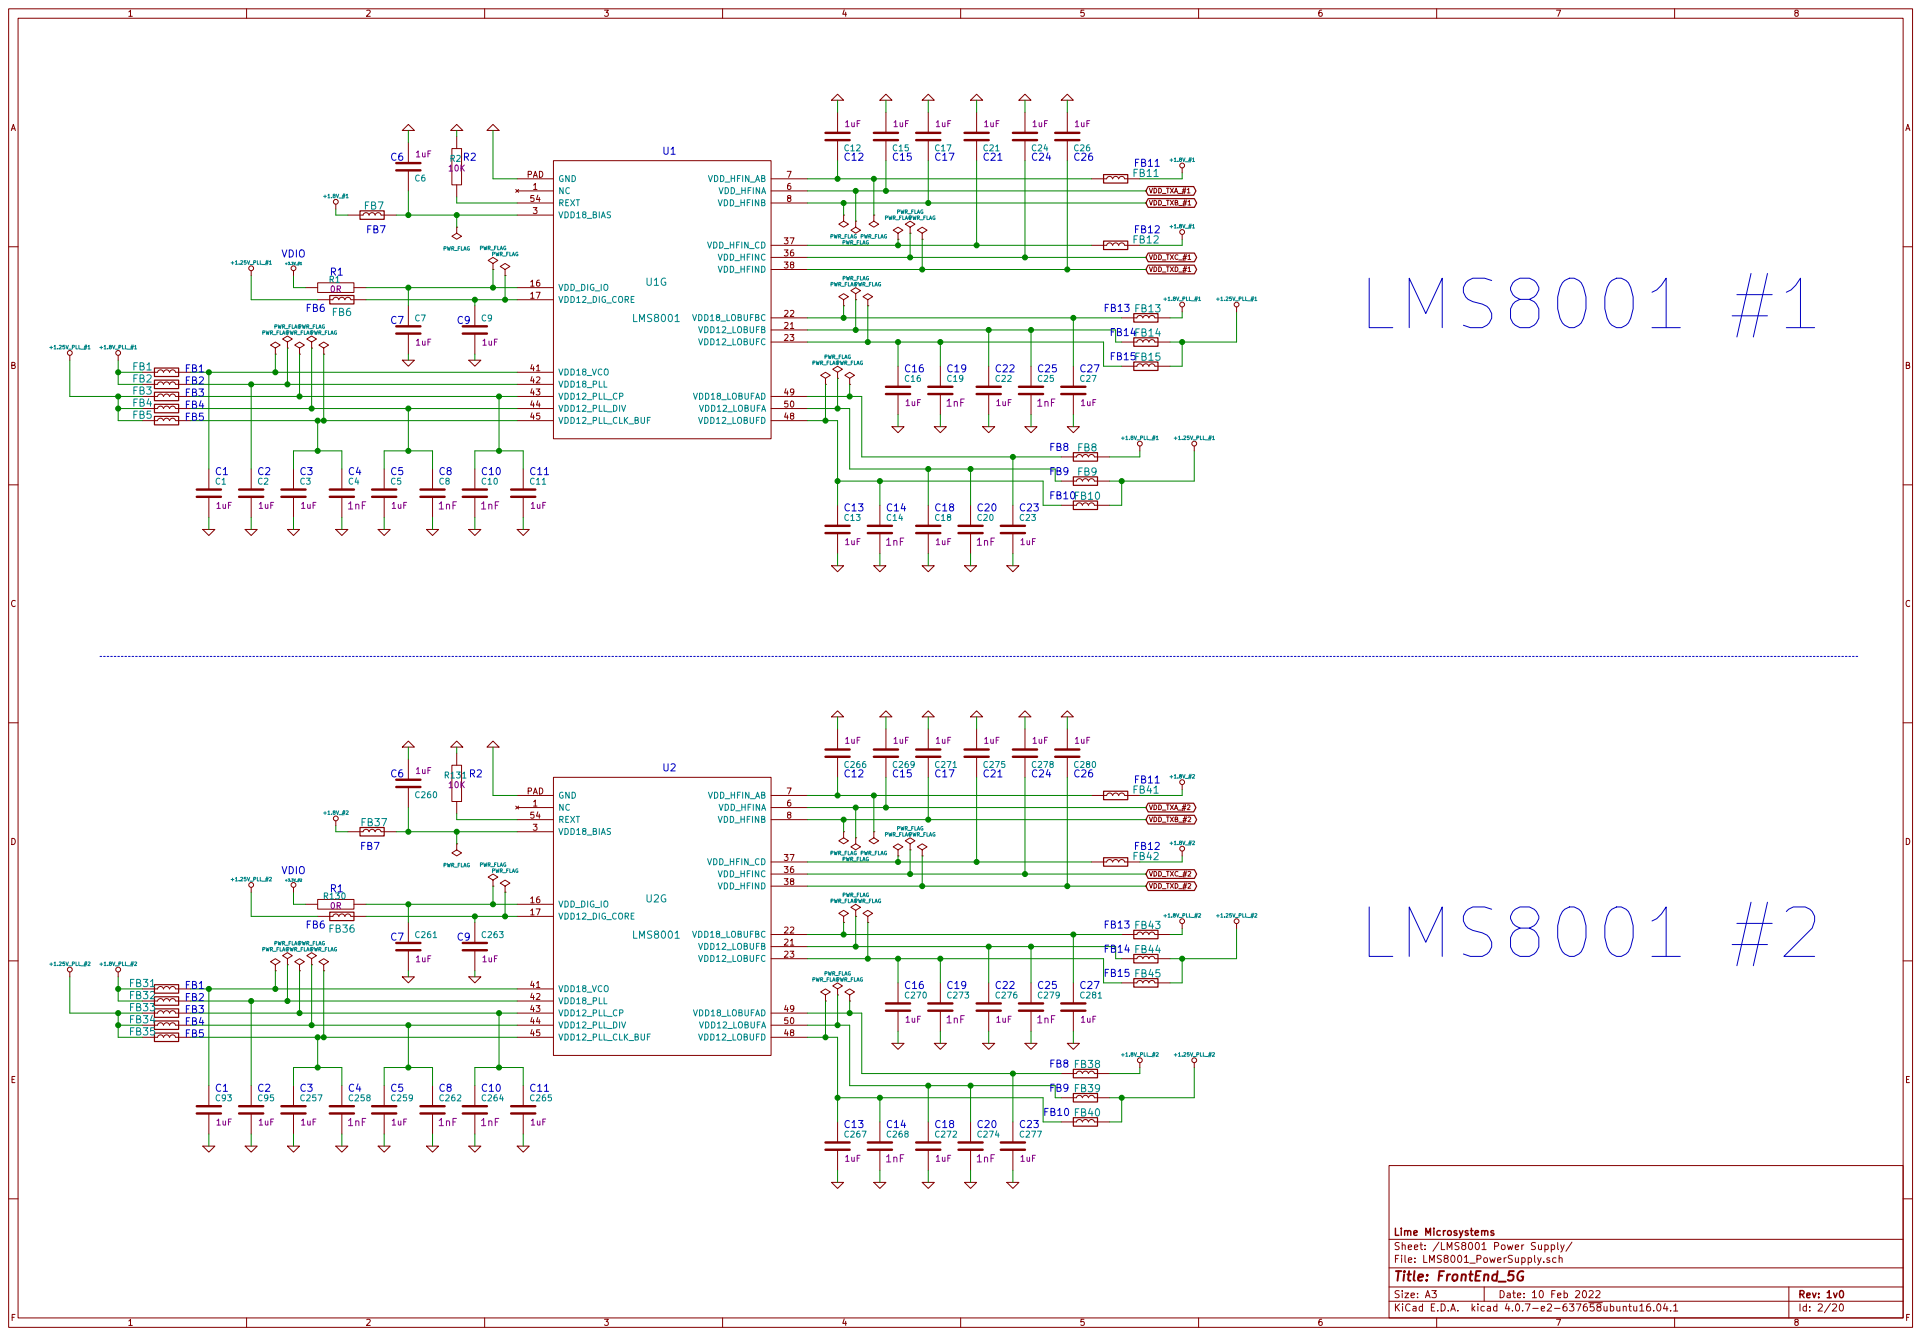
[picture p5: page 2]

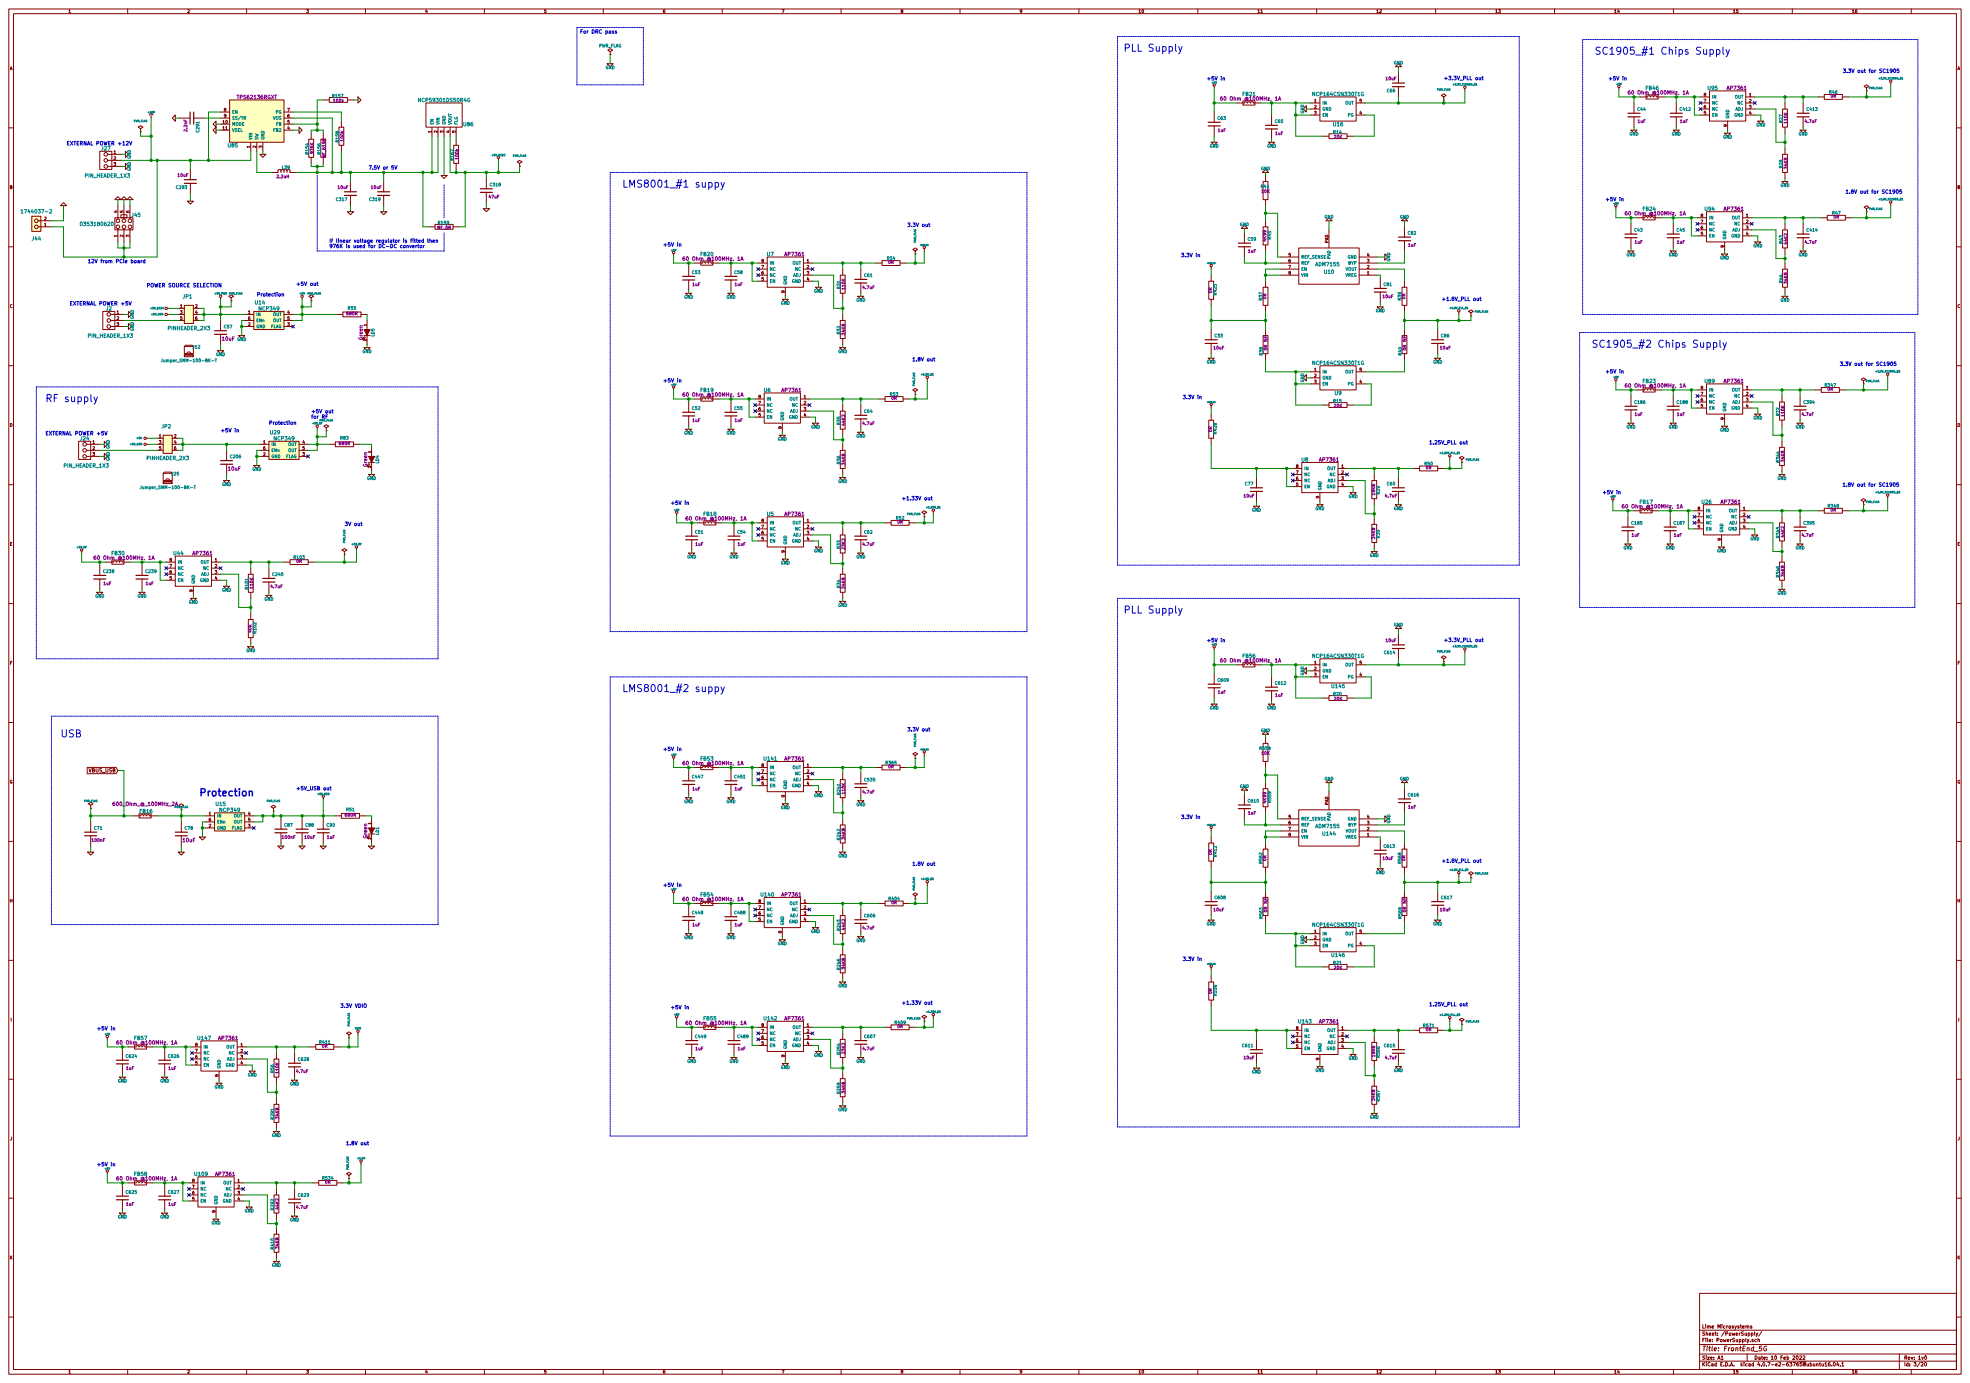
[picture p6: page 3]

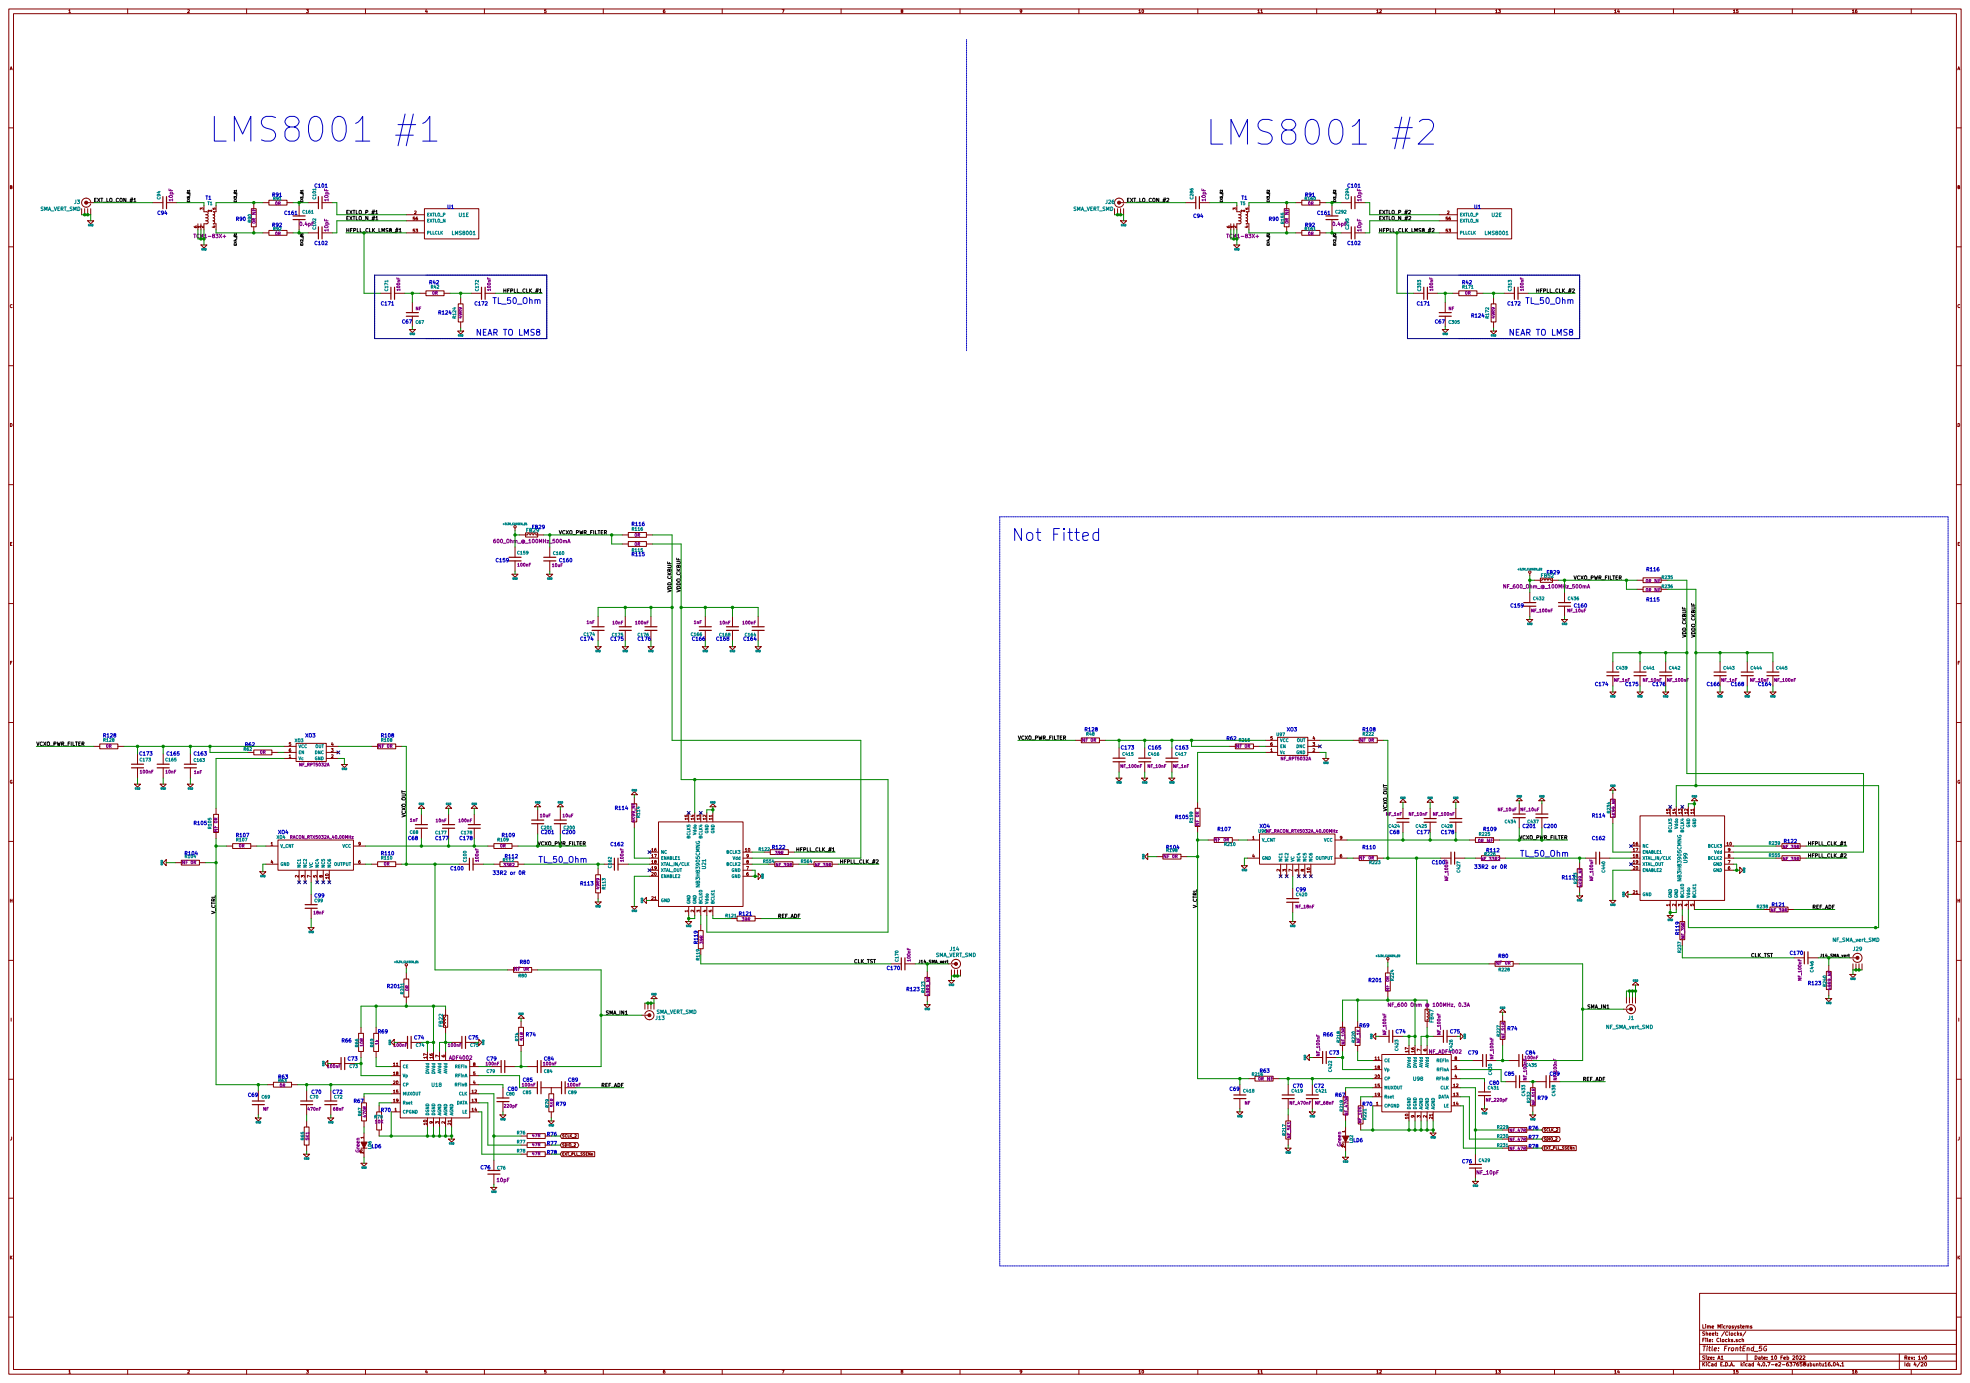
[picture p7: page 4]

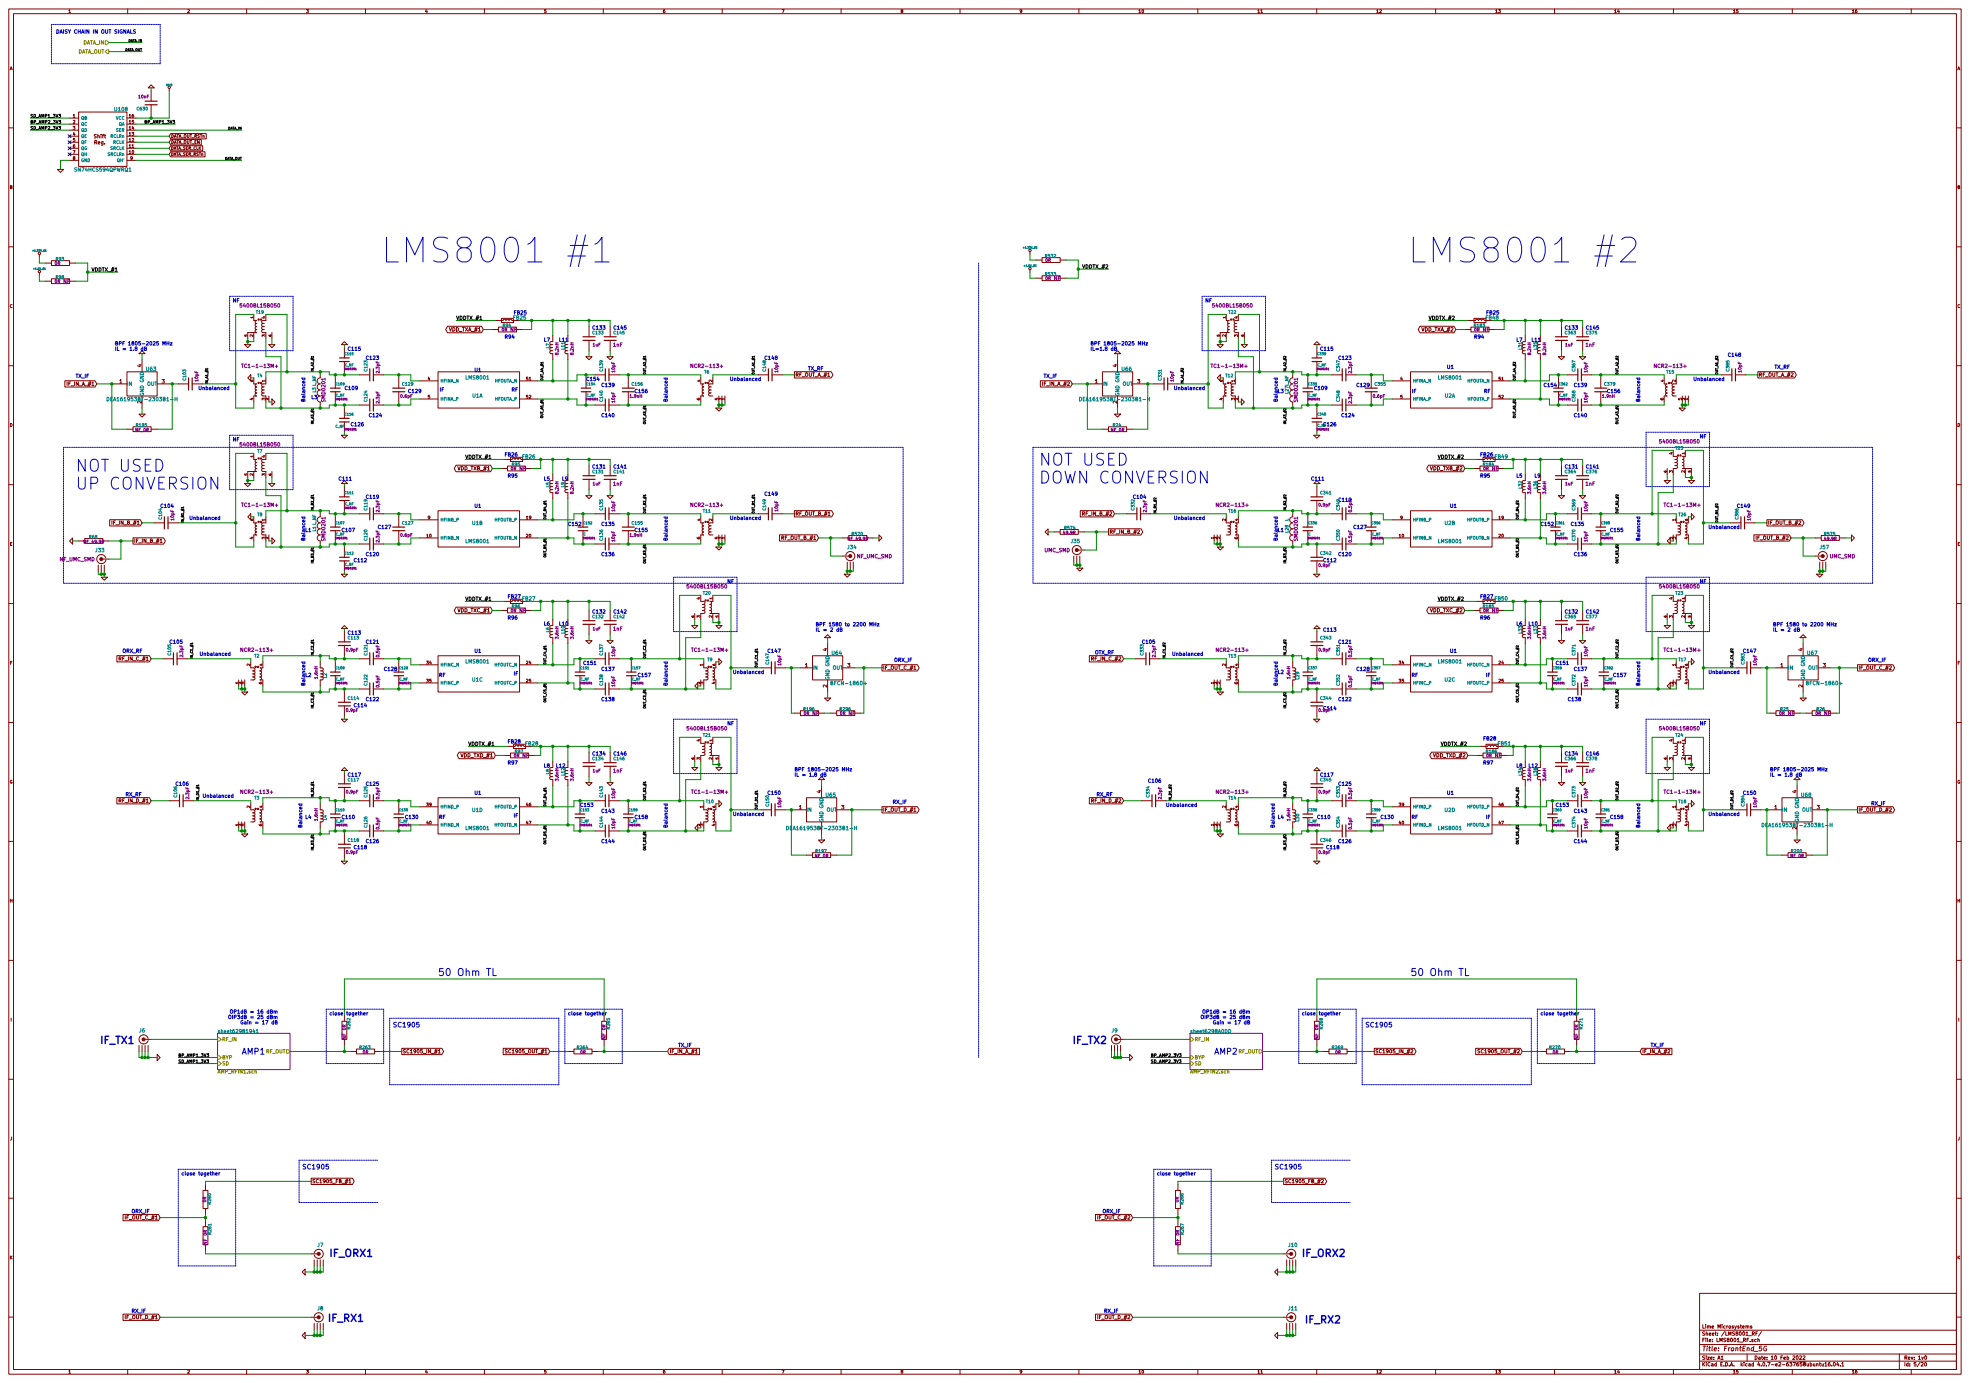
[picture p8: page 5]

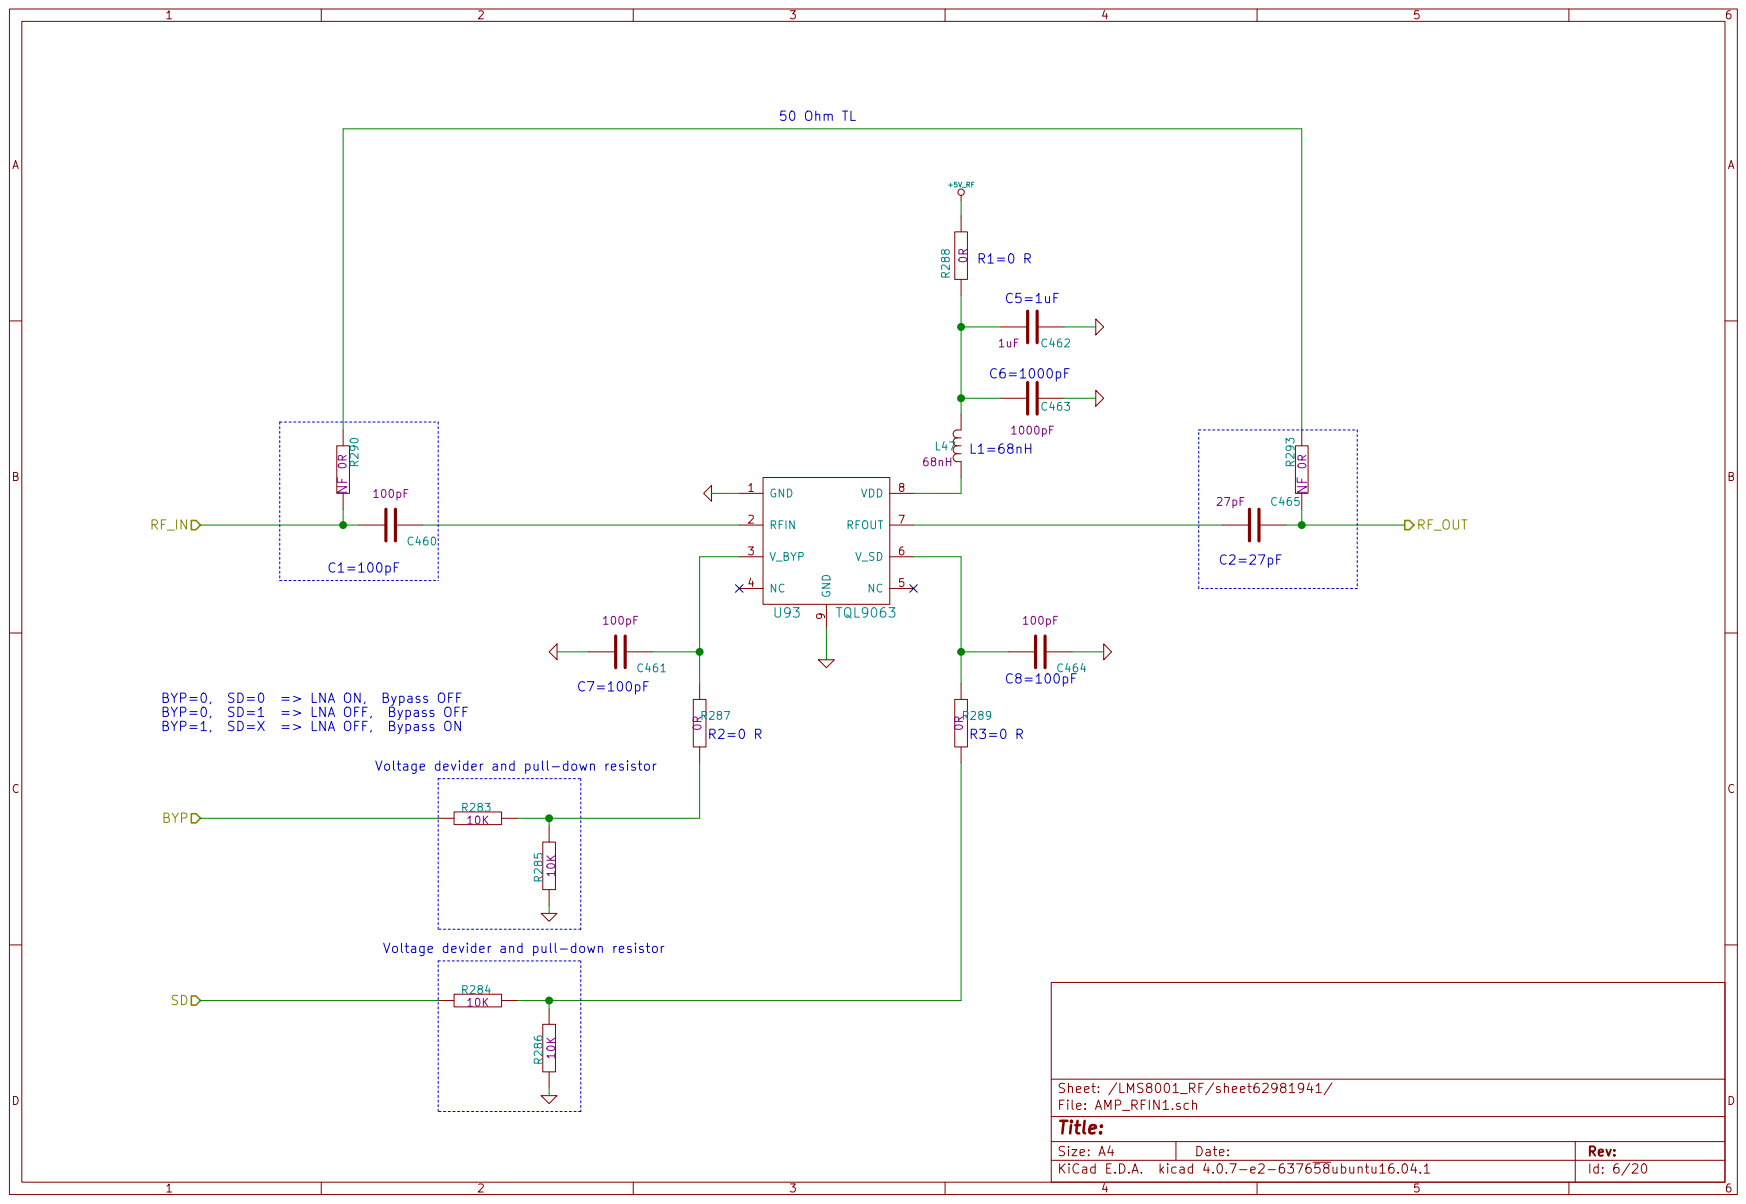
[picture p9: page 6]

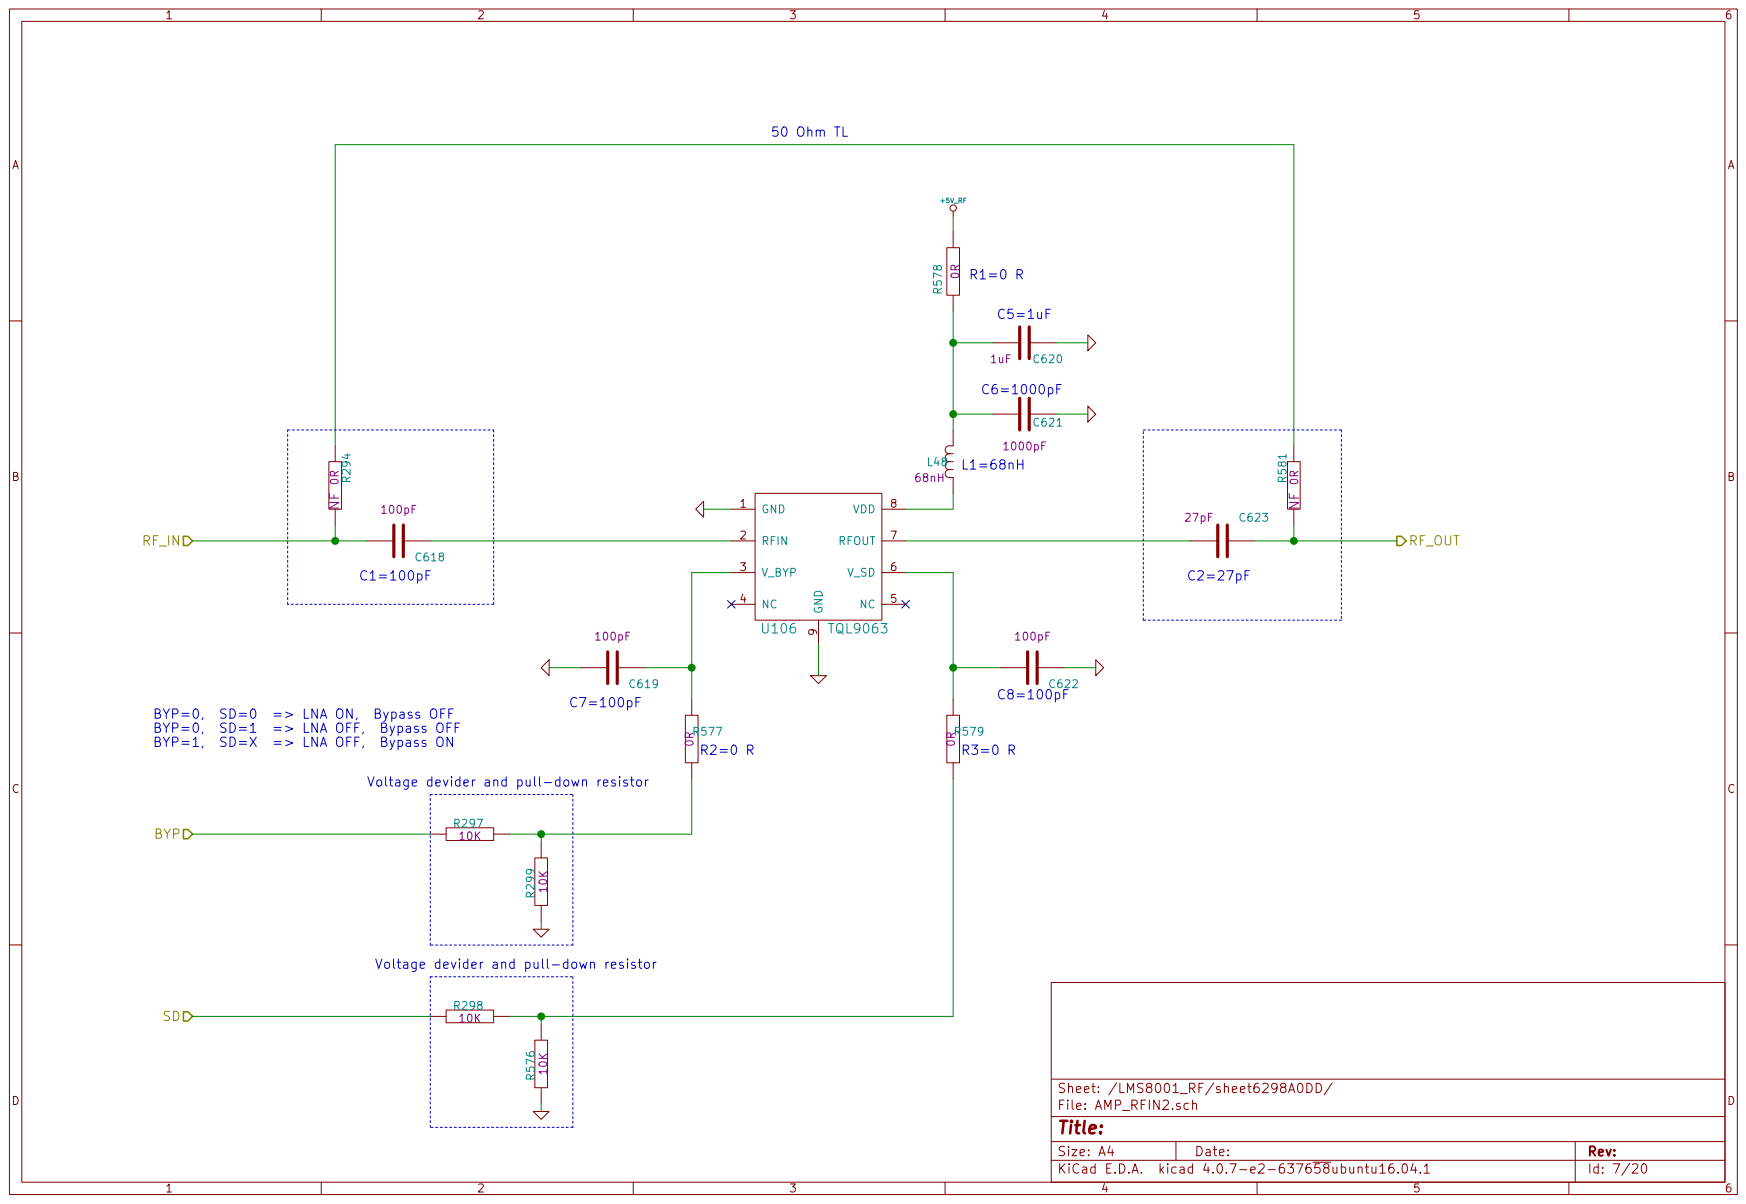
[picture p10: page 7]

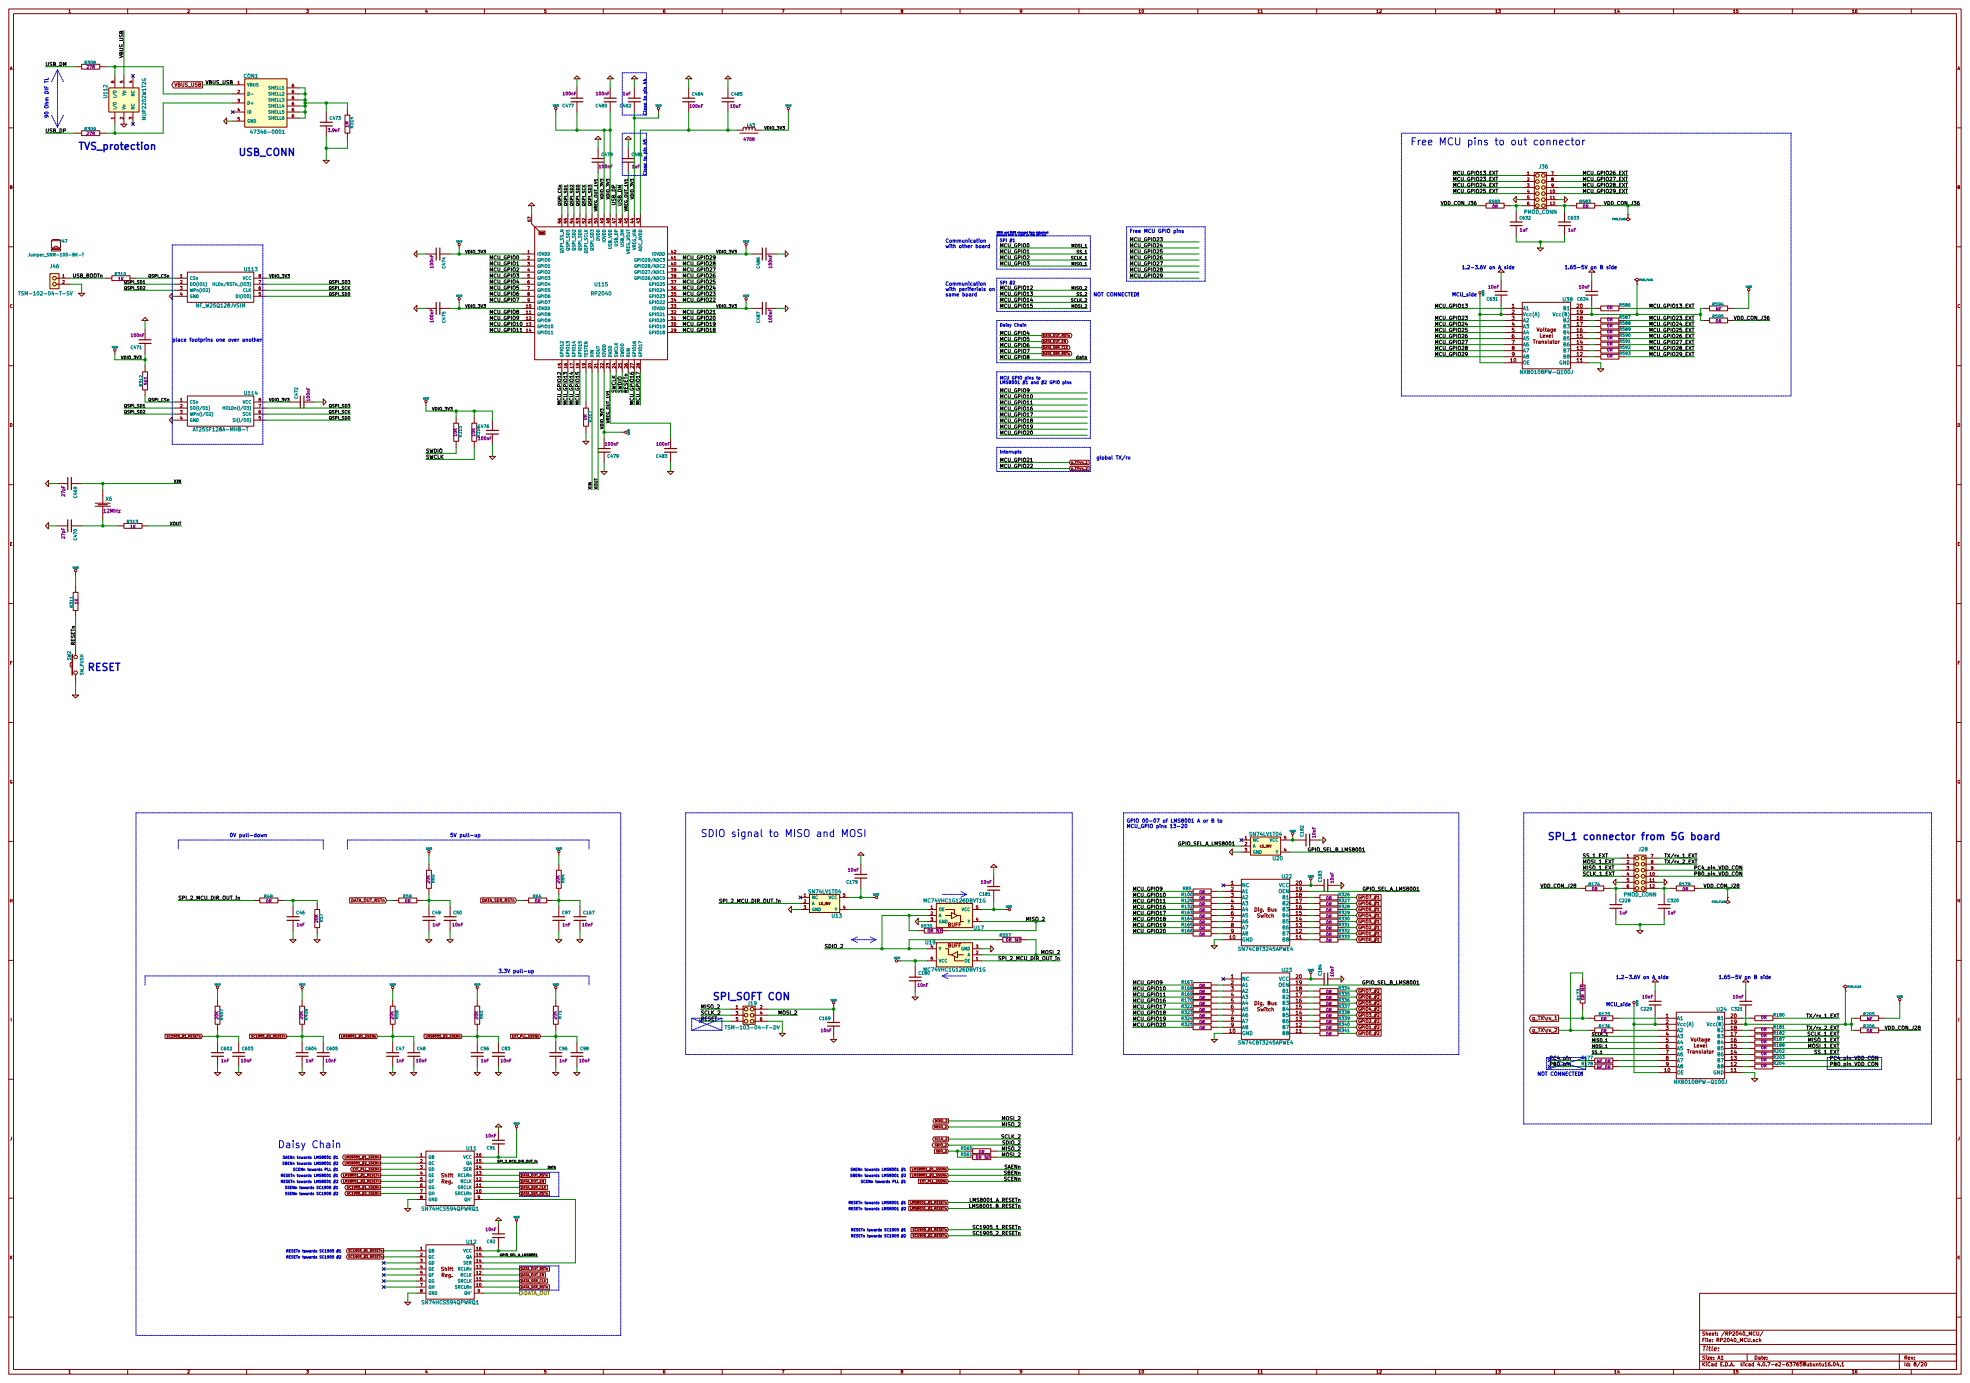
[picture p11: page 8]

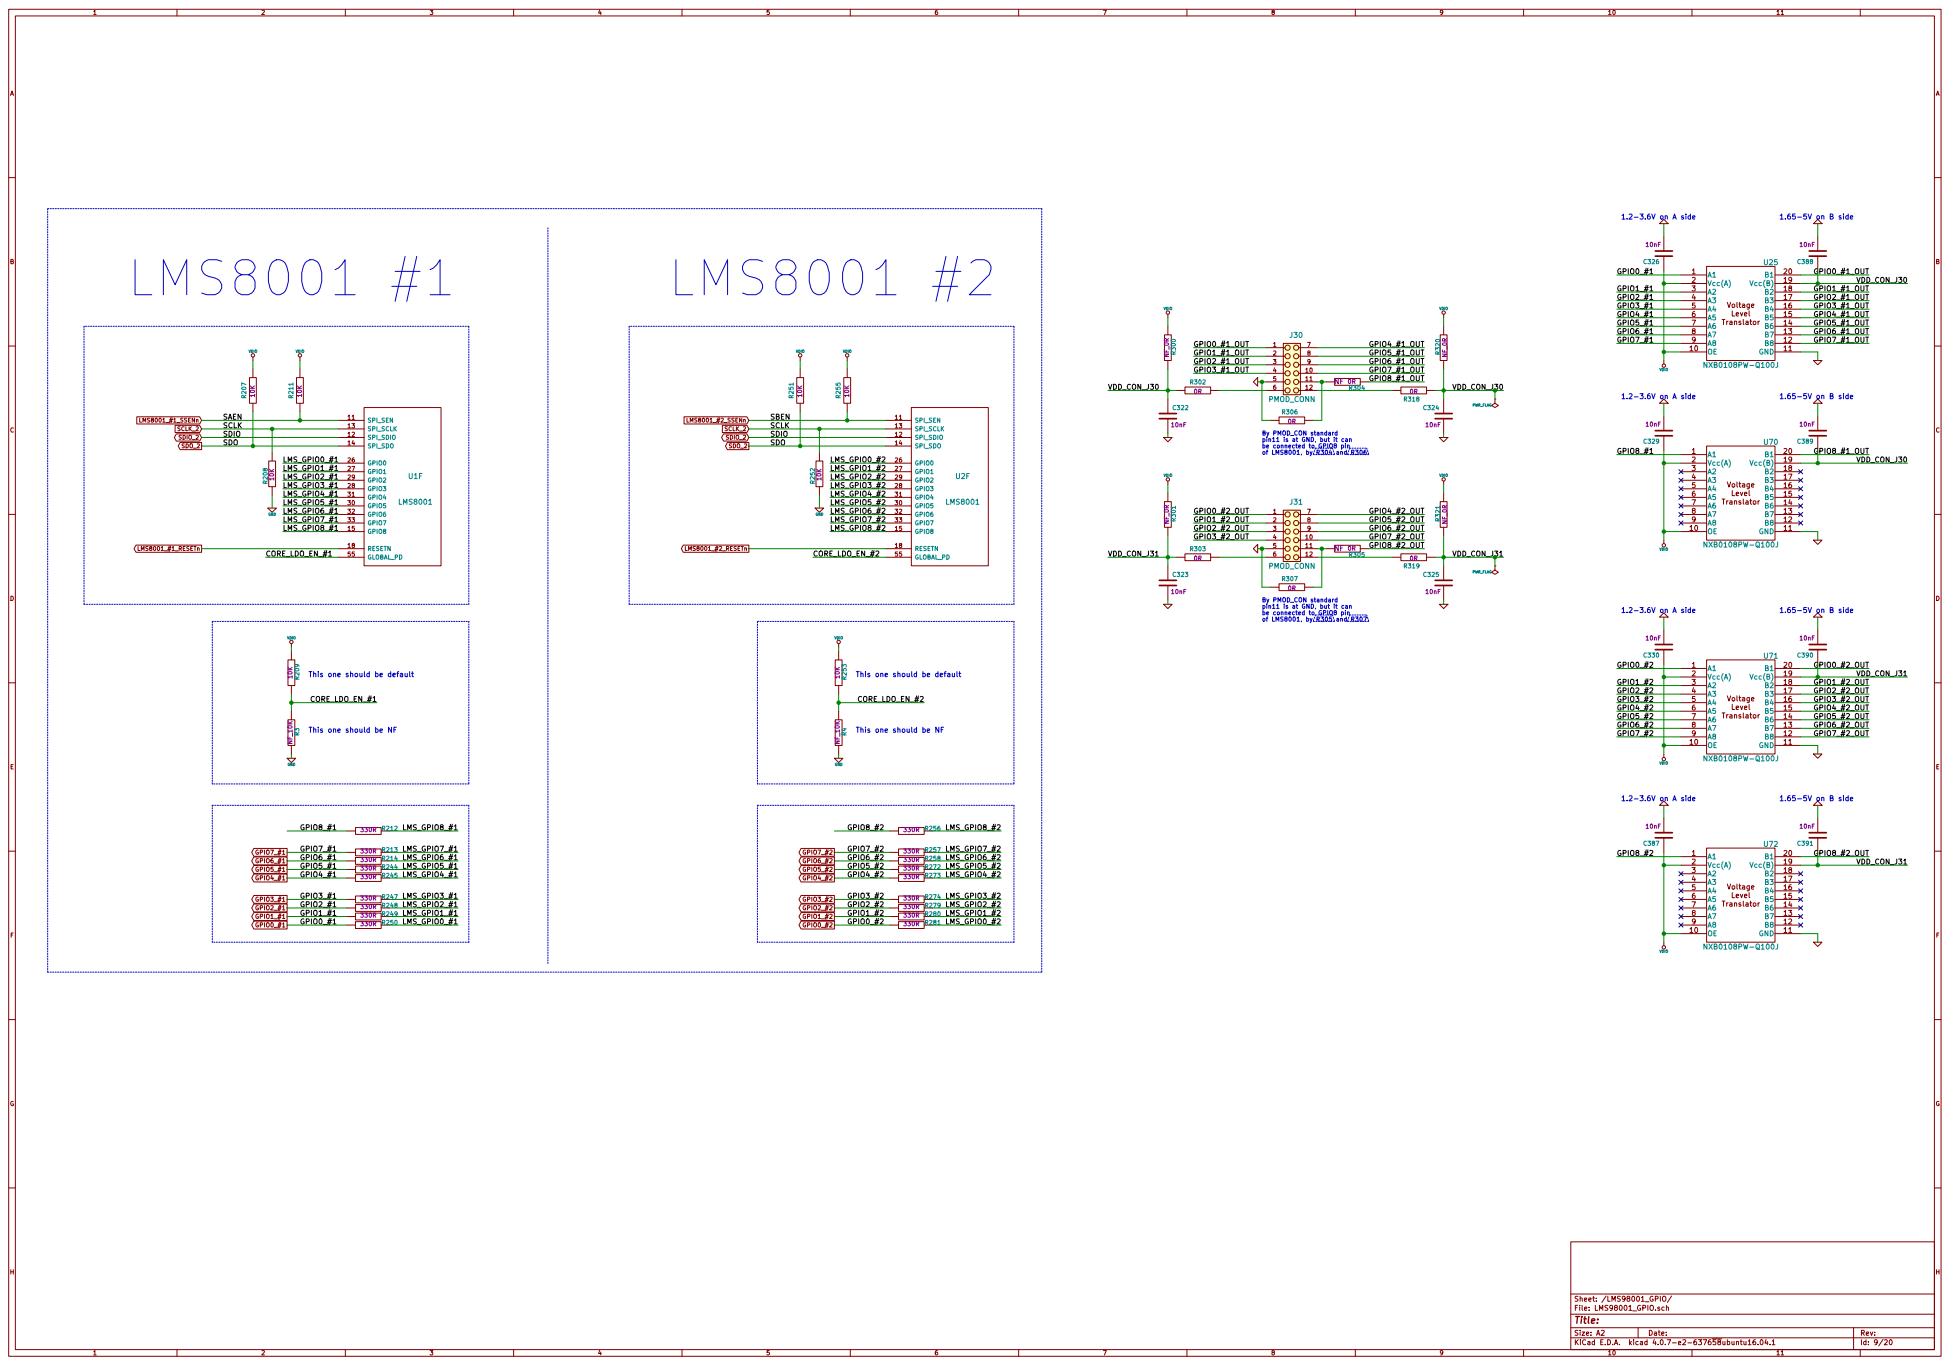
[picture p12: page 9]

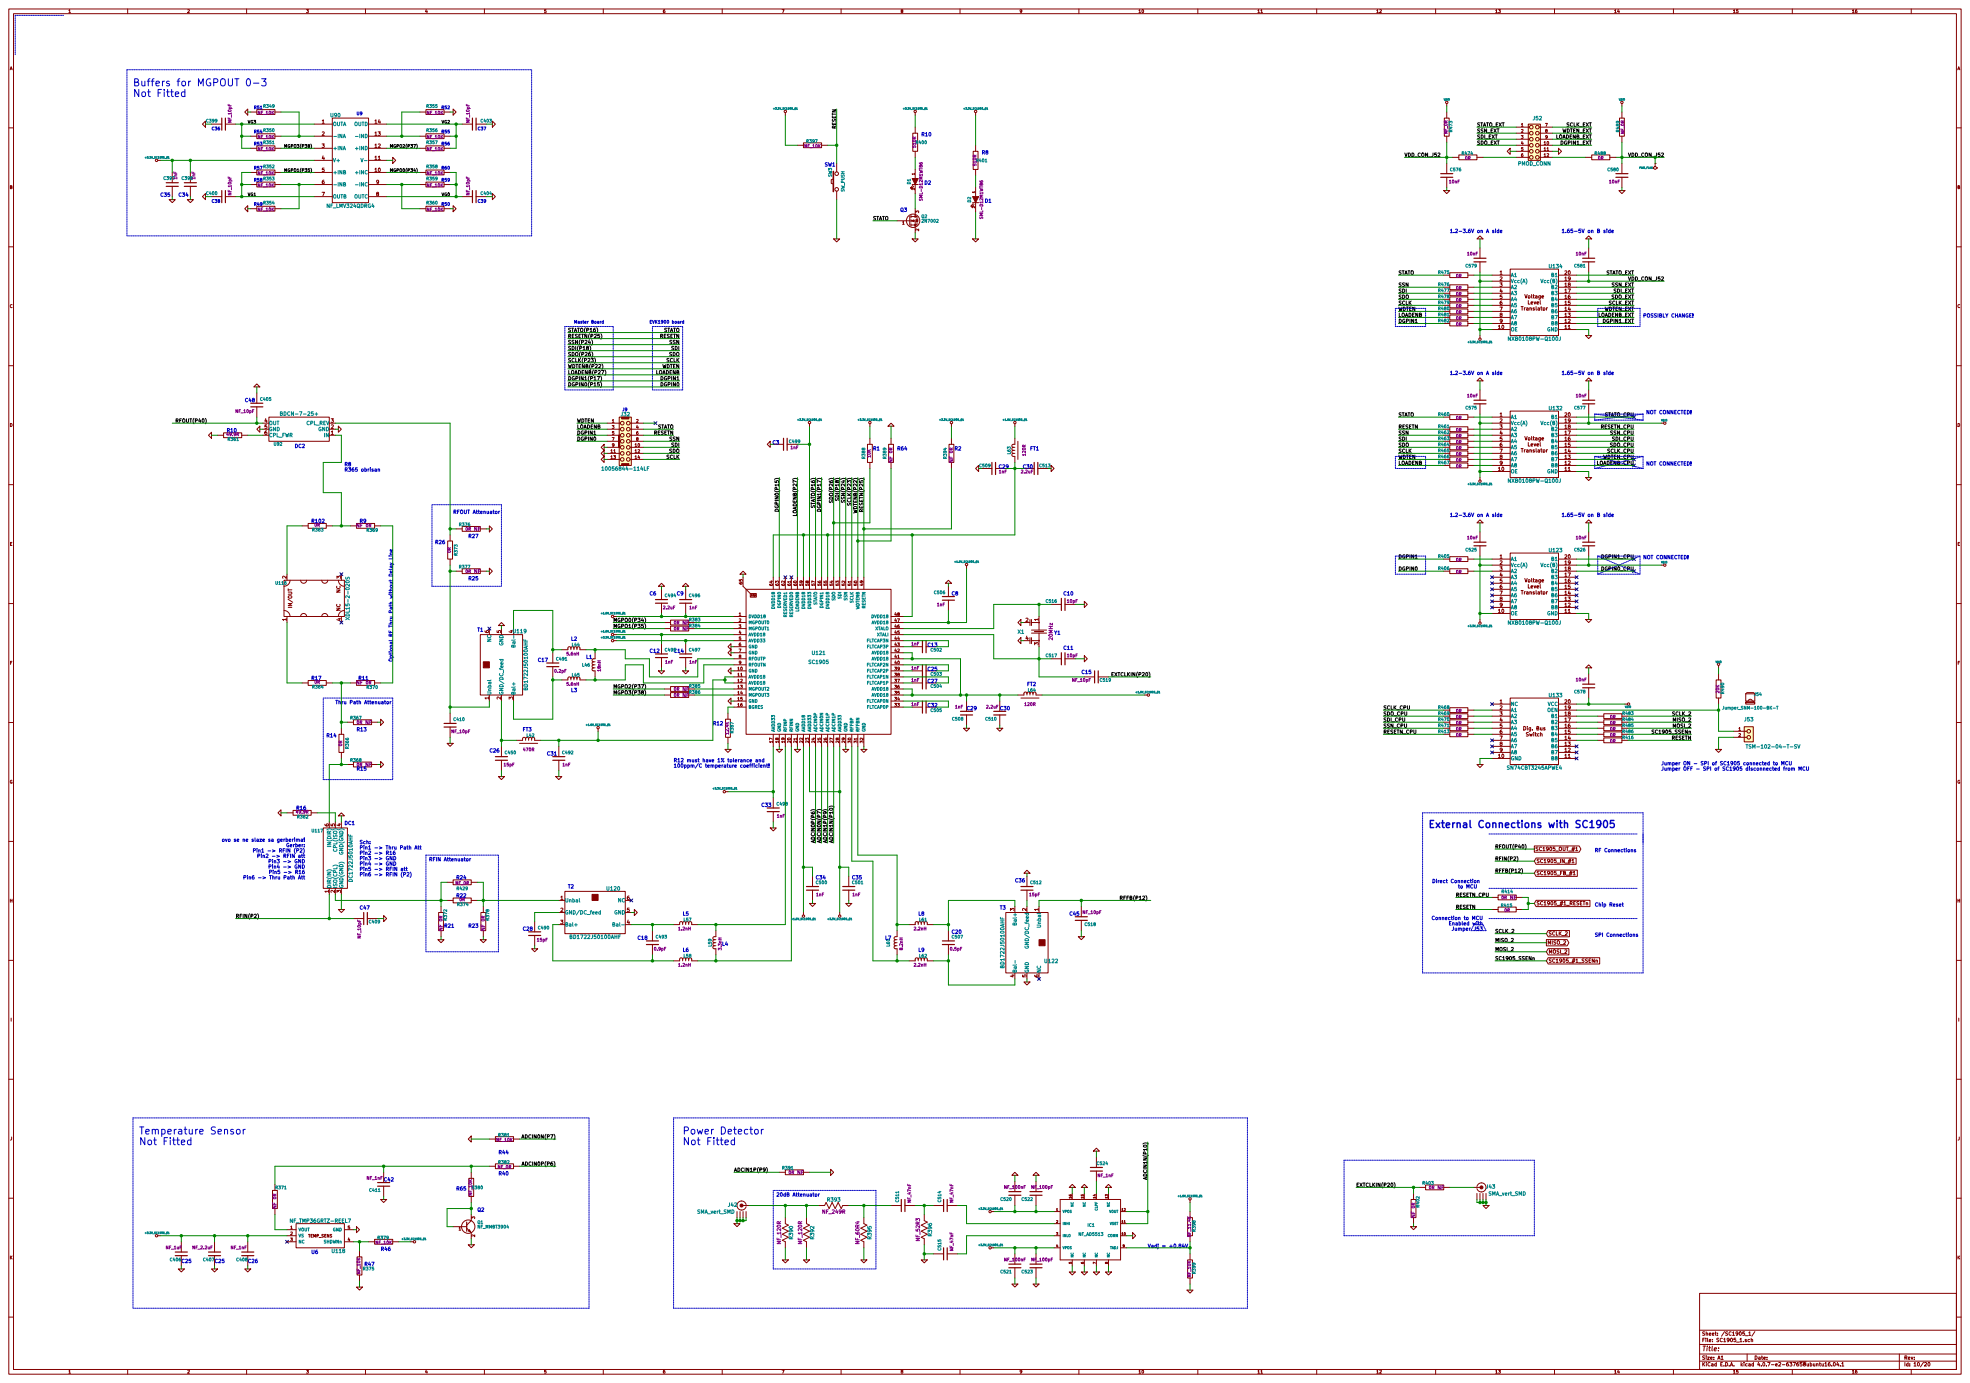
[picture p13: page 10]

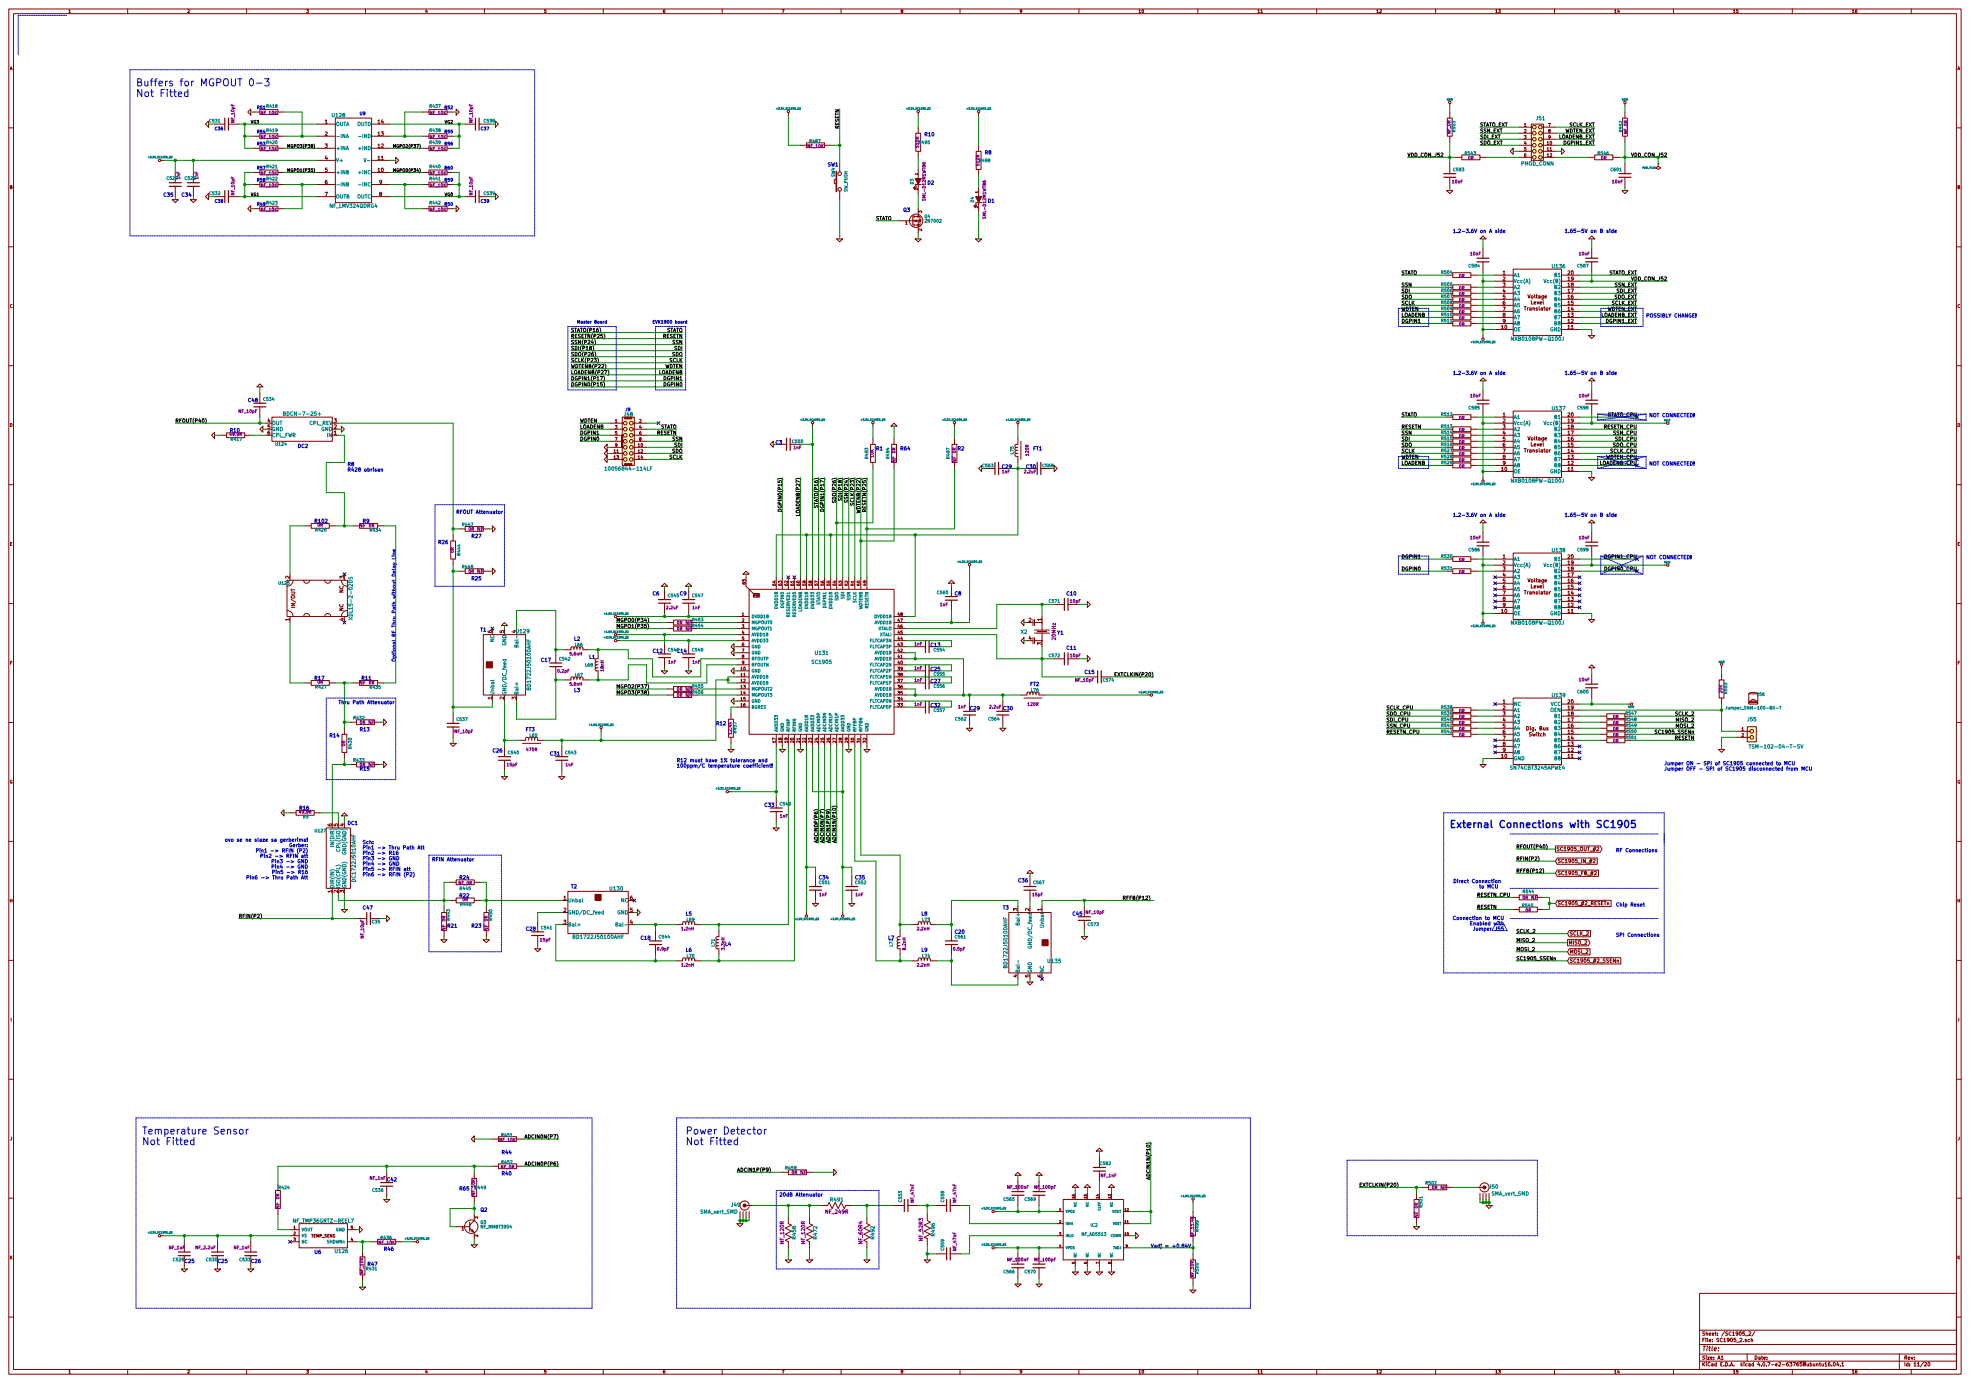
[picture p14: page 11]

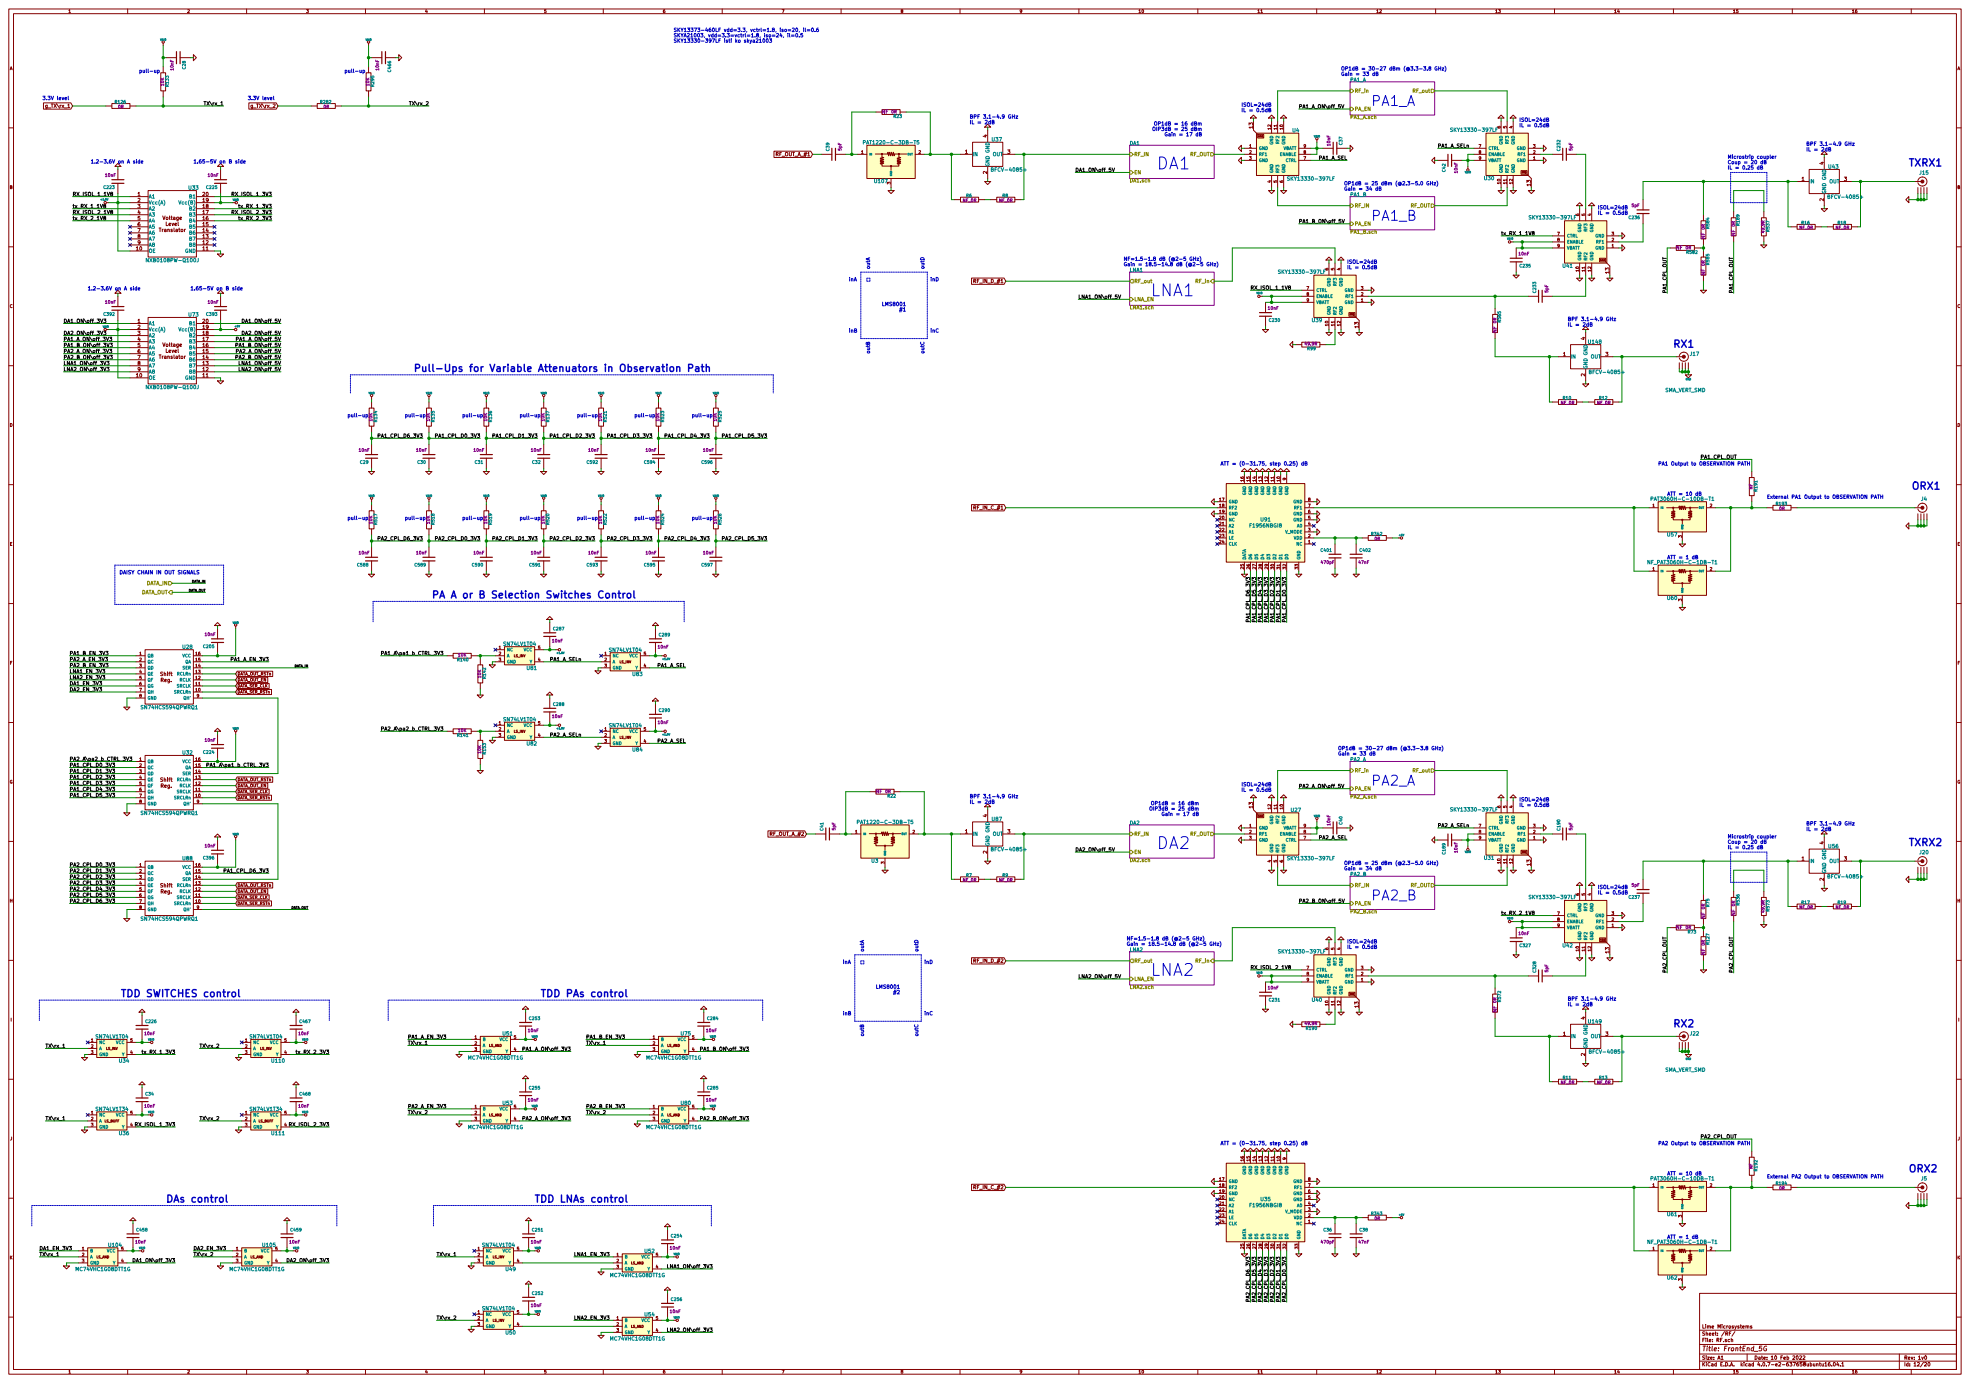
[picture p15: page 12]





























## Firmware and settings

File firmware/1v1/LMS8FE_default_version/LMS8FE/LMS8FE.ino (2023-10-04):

#include "mcu.h"
#include "consts.h"
#include "chain.h"
#include "cmd.h"
#include "errorCode.h"

#include <stdio.h>
#include "pico/stdlib.h"
#include "hardware/spi.h"

// milans 220616
#include "LMS64C_protocol.h"

#define SPIMASTER spi1
#define SPISLAVE spi0

#define SPIMASTER_RX 12
// #define SPIMASTER_CSN  13
#define SPIMASTER_CLK 14
#define SPIMASTER_TX 15

#define SPISLAVE_RX 0
#define SPISLAVE_CSN 1
#define SPISLAVE_CLK 2
#define SPISLAVE_TX 3

#define SC1905_ACK0 0x0F
#define SC1905_ACK1 0xF0

#define SC1905_RSR_READ_ATTEMPTS 200
#define SC1905_EEPROM_STATUS_ATTEMPTS 200

// milans 220615
// uint8_t activeBuffer[BUFFER_SIZE];
// uint8_t activeBufferSize = BUFFER_SIZE;
uint8_t activeBuffer[BUFFER_SIZE_LMS8001];
uint8_t activeBufferSize = BUFFER_SIZE_LMS8001;

// milans 220615
// uint8_t out_buf0[BUFFER_SIZE], in_buf0[BUFFER_SIZE];
// uint8_t out_buf1[BUFFER_SIZE], in_buf1[BUFFER_SIZE];
uint8_t out_buf0[BUFFER_SIZE_LMS8001], in_buf0[BUFFER_SIZE_LMS8001];
uint8_t out_buf1[BUFFER_SIZE_LMS8001], in_buf1[BUFFER_SIZE_LMS8001];

unsigned char activeState[STATE_SIZE];
unsigned char nextState[STATE_SIZE];

unsigned char activeChannel;

// int periphID;

unsigned char diodeState = 0;
/************   LMS8001 functions - Start   ************/
#define TRUE 1
#define FALSE 0

uint8_t activeBufferLMS8001tx[BUFFER_SIZE_LMS8001];

tLMS_Ctrl_Packet *LMS_Ctrl_Packet_Tx = (tLMS_Ctrl_Packet *)activeBufferLMS8001tx;
tLMS_Ctrl_Packet *LMS_Ctrl_Packet_Rx = (tLMS_Ctrl_Packet *)activeBuffer;

uint8_t block, cmd_errors;

uint16_t maddress = 0x00AA;
uint16_t maddress2 = 0x00AB;

// B.J.
uint8_t BuffLMS8FE[64];
uint8_t RegLMS8FE[2];
uint8_t RDbyteX[128]; // for debugging
int wrPtr = 0;        // for debugging
int rdPtr = 0;        // for debugging
uint8_t spi_state = 0;
uint16_t maddr = 0x00;
uint16_t faddr = 0x00;
uint16_t w_nr = 0x00;
uint8_t FlagX = 0;
uint8_t X10, X1 = 0;
uint16_t src = 0x0000;
uint16_t dst = 0x0000;
// end B.J.

uint8_t SPI1_transfer_byte(uint8_t cmd)
{
  uint8_t result;
  /*
      while (SPI_I2S_GetFlagStatus(SPI1, SPI_I2S_FLAG_TXE) == RESET); //Wait until the transmit buffer is empty
      SPI_I2S_SendData(SPI1, cmd);
      //while (SPI_I2S_GetFlagStatus(SPI1, SPI_I2S_FLAG_BSY) == SET); //wait finish sending

      while(SPI_I2S_GetFlagStatus(SPI1, SPI_I2S_FLAG_RXNE) == RESET); // wait data received

      result = SPI_I2S_ReceiveData(SPI1);
  */

  spi_write_read_blocking(SPIMASTER, &cmd, &result, 1);

  return result;
}

/**  This function checks if all blocks could fit in data field.
  If blocks will not fit, function returns TRUE. */
unsigned char Check_many_blocks(unsigned char block_size)
{
  if (LMS_Ctrl_Packet_Rx->Header.Data_blocks > (sizeof(LMS_Ctrl_Packet_Tx->Data_field) / block_size))
  {
    LMS_Ctrl_Packet_Tx->Header.Status = STATUS_BLOCKS_ERROR_CMD;
    return TRUE;
  }
  else
    return FALSE;
  return FALSE;
}
/************   LMS8001 functions - End   ************/

void cs_setval(int periphID, uint8_t val)
{
  uint8_t targetByte;
  uint8_t targetBit;

  switch (periphID)
  {
  case PERIPH_SC1905:
    if (activeChannel == 0)
    {
      targetByte = SC1905_1_SSENn_BYTE;
      targetBit = SC1905_1_SSENn_BIT;
    }
    else
    {
      targetByte = SC1905_2_SSENn_BYTE;
      targetBit = SC1905_2_SSENn_BIT;
    }
    break;
  case PERIPH_LMS8001:
    if (activeChannel == 0)
    {
      targetByte = LMS8001_1_SSENn_BYTE;
      targetBit = LMS8001_1_SSENn_BIT;
    }
    else
    {
      targetByte = LMS8001_2_SSENn_BYTE;
      targetBit = LMS8001_2_SSENn_BIT;
    }
    break;
  case PERIPH_ADF4002:
    targetByte = EXT_PLL_SSENn_BYTE;
    targetBit = EXT_PLL_SSENn_BIT;
    break;
  default:
    // Implement error handling
    return;
  }
  setChainBit(targetByte, targetBit, val, activeState, nextState);
  setState(nextState);
}

void cs_select(int periphID)
{
  // Here implement the CSEN = 0 for the periphery provided as parameter
  // This is just a temporary solution
  //    asm volatile("nop \n nop \n nop");
  //    gpio_put(SPIMASTER_CSN, 0);  // Active low
  //    asm volatile("nop \n nop \n nop");
  cs_setval(periphID, 0);
}

void cs_deselect(int periphID)
{
  // Here implement the CSEN = 1 for the periphery provided as parameter
  // This is just a temporary solution
  //    asm volatile("nop \n nop \n nop");
  //    gpio_put(SPIMASTER_CSN, 1);
  //    asm volatile("nop \n nop \n nop");
  cs_setval(periphID, 1);
}

/*
  static inline void cs_select() {
    asm volatile("nop \n nop \n nop");
    gpio_put(SPIMASTER_CSN, 0);  // Active low
    asm volatile("nop \n nop \n nop");
  }

  static inline void cs_deselect() {
    asm volatile("nop \n nop \n nop");
    gpio_put(SPIMASTER_CSN, 1);
    asm volatile("nop \n nop \n nop");
  }
*/

int loadenbSC1905pin()
{
  if (activeChannel == 0)
    return LOADENB_SC1905_1_PIN;
  else
    return LOADENB_SC1905_2_PIN;
}

void test_irq_handler(uint gpio, uint32_t events)
{
  gpio_set_irq_enabled(29, GPIO_IRQ_EDGE_FALL, false);

  // B.J.
  FlagX = 1;

  gpio_set_irq_enabled(29, GPIO_IRQ_EDGE_FALL, true);
}

int sc1905_message_protocol(uint8_t *mrb, uint8_t *mrb_rcv)
{

  uint8_t lastRSR = 0x00;

  // RSR Read Command
  out_buf0[0] = 0xC8;
  out_buf0[1] = 0x00;
  out_buf0[2] = 0x28;
  out_buf0[3] = 0x00;

  cs_select(PERIPH_SC1905);
  spi_write_read_blocking(SPIMASTER, out_buf0, in_buf0, 4);
  cs_deselect(PERIPH_SC1905);
  sleep_ms(10);

  lastRSR = in_buf0[3];

  if (!((lastRSR == 0x00) || (lastRSR == SC1905_ACK0) || (lastRSR == SC1905_ACK1)))
  {
    return ERROR_SC1905_RSR;
  }

  //  uint8_t mrb[4];

  uint8_t bytesCode = 0x00;

  uint8_t chk = ~((mrb[0] + mrb[1] + mrb[2] + mrb[3]) % 256);

  // CHK Write Command
  clearBuffer(out_buf0);
  out_buf0[0] = 0xD5;
  out_buf0[1] = 0x81;
  out_buf0[2] = 0x20;
  out_buf0[3] = chk;

  cs_select(PERIPH_SC1905);
  spi_write_read_blocking(SPIMASTER, out_buf0, in_buf0, 4);
  cs_deselect(PERIPH_SC1905);
  sleep_ms(10);

  // MRB Write Command
  clearBuffer(out_buf0);
  out_buf0[0] = 0xF0;
  out_buf0[1] = 0x00;
  out_buf0[2] = 0x20;
  out_buf0[3] = mrb[0];
  out_buf0[4] = mrb[1];
  out_buf0[5] = mrb[2];
  out_buf0[6] = mrb[3];

  cs_select(PERIPH_SC1905);
  spi_write_read_blocking(SPIMASTER, out_buf0, in_buf0, 7);
  cs_deselect(PERIPH_SC1905);
  sleep_ms(10);

  int i = 0;

  // RSR Read Command
  clearBuffer(out_buf0);
  out_buf0[0] = 0xC8;
  out_buf0[1] = 0x00;
  out_buf0[2] = 0x28;

  bool success = false;
  while (i < SC1905_RSR_READ_ATTEMPTS)
  {
    cs_select(PERIPH_SC1905);
    spi_write_read_blocking(SPIMASTER, out_buf0, in_buf0, 4);
    cs_deselect(PERIPH_SC1905);

    uint8_t newRSR = in_buf0[3];

    if (((newRSR == SC1905_ACK0) || (newRSR == SC1905_ACK1)) && (newRSR != lastRSR))
    {
      lastRSR = newRSR;
      success = true;
      break;
    }

    sleep_ms(5);
    i++;
  }

  if (!success)
  {
    return ERROR_SC1905_RSR;
  }

  // MRB Read Command
  clearBuffer(out_buf0);
  out_buf0[0] = 0xF0;
  out_buf0[1] = 0x00;
  out_buf0[2] = 0x28;

  cs_select(PERIPH_SC1905);
  spi_write_read_blocking(SPIMASTER, out_buf0, in_buf0, 7);
  cs_deselect(PERIPH_SC1905);
  sleep_ms(10);

  mrb_rcv[0] = in_buf0[3];
  mrb_rcv[1] = in_buf0[4];
  mrb_rcv[2] = in_buf0[5];
  mrb_rcv[3] = in_buf0[6];

  // CHK Read Command
  clearBuffer(out_buf0);
  out_buf0[0] = 0xD5;
  out_buf0[1] = 0x81;
  out_buf0[2] = 0x28;

  cs_select(PERIPH_SC1905);
  spi_write_read_blocking(SPIMASTER, out_buf0, in_buf0, 4);
  cs_deselect(PERIPH_SC1905);
  sleep_ms(10);

  chk = in_buf0[3];

  uint8_t read_chk = ~((mrb_rcv[0] + mrb_rcv[1] + mrb_rcv[2] + mrb_rcv[3] + lastRSR) % 256);

  if (chk != read_chk)
  {
    return ERROR_SC1905_CHK;
  }

  return COMPLETED;
}

void sc1905_Reset()
{
  //  gpio_put(RESETN_SC1904_PIN, 0);
  //  sleep_ms(100);
  //  gpio_put(RESETN_SC1904_PIN, 1);

  uint8_t targetByte;
  uint8_t targetBit;

  if (activeChannel == 0)
  {
    targetByte = SC1905_1_RESETn_BYTE;
    targetBit = SC1905_1_RESETn_BIT;
  }
  else
  {
    targetByte = SC1905_2_RESETn_BYTE;
    targetBit = SC1905_2_RESETn_BIT;
  }

  setChainBit(targetByte, targetBit, 0, activeState, nextState);
  setState(nextState);
  sleep_ms(100);
  setChainBit(targetByte, targetBit, 1, activeState, nextState);
  setState(nextState);
}

int sc1905_EEPROM_Read(uint8_t *cmd_buf)
{
  uint8_t bytesNo = cmd_buf[4];
  clearBuffer(out_buf0);
  out_buf0[0] = 0x03;
  out_buf0[1] = cmd_buf[2];
  out_buf0[2] = cmd_buf[3];
  //    gpio_put(LOADENB_SC1904_1_PIN, 1);
  gpio_put(loadenbSC1905pin(), 1);

  cs_select(PERIPH_SC1905);
  spi_write_read_blocking(SPIMASTER, out_buf0, in_buf0, 3 + bytesNo);
  cs_deselect(PERIPH_SC1905);
  sleep_ms(10);

  //    gpio_put(LOADENB_SC1904_1_PIN, 0);
  gpio_put(loadenbSC1905pin(), 0);

  cmd_buf[1] = in_buf0[3];
  if (bytesNo == 2)
    cmd_buf[2] = in_buf0[4];

  return COMPLETED;
}

int sc1905_EEPROM(uint8_t *cmd_buf)
{
  uint8_t isRead = cmd_buf[1];

  if (isRead == 1)
  {
    // Read
    sc1905_EEPROM_Read(cmd_buf);
    /*
        uint8_t bytesNo = cmd_buf[4];
        clearBuffer(out_buf0);
        out_buf0[0] = 0x03;
        out_buf0[1] = cmd_buf[2];
        out_buf0[2] = cmd_buf[3];
    //    gpio_put(LOADENB_SC1904_1_PIN, 1);
        gpio_put(loadenbSC1905pin(), 1);

        cs_select(PERIPH_SC1905);
        spi_write_read_blocking(SPIMASTER, out_buf0, in_buf0, 3 + bytesNo);
        cs_deselect(PERIPH_SC1905);
        sleep_ms(10);

    //    gpio_put(LOADENB_SC1904_1_PIN, 0);
        gpio_put(loadenbSC1905pin(), 0);

        cmd_buf[1] = in_buf0[3];
        if (bytesNo == 2)
          cmd_buf[2] = in_buf0[4];
    */
  }
  else
  {
    // Write
    uint8_t tmp_buf[BUFFER_SIZE];
    // Read original values, will be needed for checksum calculation
    memcpy(tmp_buf, cmd_buf, sizeof(cmd_buf[0]) * BUFFER_SIZE);
    sc1905_EEPROM_Read(tmp_buf);
    uint8_t original_values[2];
    original_values[0] = tmp_buf[1];
    original_values[1] = tmp_buf[2];
    // Read original checksum, will be needed for checksum calculation
    tmp_buf[2] = 0xFF; // Checksum address is 0xFFFF
    tmp_buf[3] = 0xFF;
    tmp_buf[4] = 1; // Read single byte
    sc1905_EEPROM_Read(tmp_buf);
    uint8_t original_checksum = tmp_buf[1];

    // Write
    //    gpio_put(LOADENB_SC1904_1_PIN, 1);
    gpio_put(loadenbSC1905pin(), 1);

    //    clearBuffer(out_buf0);
    //    out_buf0[0] = 0x06; // WREN command to enable write operations to EEPROM
    //    out_buf0[1] = 0x01; // Write zero to STATUS register to unlock
    //    out_buf0[2] = 0x00;
    //    out_buf0[3] = 0x05; // Read STATUS register to make sure EEPROM is UNLOCKED

    //    cs_select();
    //    spi_write_read_blocking(SPIMASTER, out_buf0, in_buf0, 5);
    //    cs_deselect();
    //    sleep_ms(10);

    //    uint8_t statusRegister = in_buf0[4];

    clearBuffer(out_buf0);
    out_buf0[0] = 0x06; // WREN command to enable write operations to EEPROM

    cs_select(PERIPH_SC1905);
    spi_write_read_blocking(SPIMASTER, out_buf0, in_buf0, 1);
    cs_deselect(PERIPH_SC1905);
    sleep_ms(10);

    clearBuffer(out_buf0);
    out_buf0[0] = 0x01; // Write zero to STATUS register to unlock
    out_buf0[1] = 0x00;

    cs_select(PERIPH_SC1905);
    spi_write_read_blocking(SPIMASTER, out_buf0, in_buf0, 2);
    cs_deselect(PERIPH_SC1905);
    sleep_ms(10);

    // milans 220809 TMP TMP TMP TMP TMP
    //     sleep_ms(1000);

    clearBuffer(out_buf0);
    out_buf0[0] = 0x05; // Read STATUS register to make sure EEPROM is UNLOCKED

    cs_select(PERIPH_SC1905);
    spi_write_read_blocking(SPIMASTER, out_buf0, in_buf0, 2);
    cs_deselect(PERIPH_SC1905);
    sleep_ms(10);

    uint8_t statusRegister = in_buf0[1];

    uint8_t wip = statusRegister & 0x01;
    bool isBusy = (wip == 1);
    uint8_t bpi01 = statusRegister & 0x0c;
    bool isLocked = (bpi01 != 0);

    if (isLocked)
    {
      cmd_buf[1] = statusRegister;

      // milans 220809
      gpio_put(loadenbSC1905pin(), 0);

      return ERROR_SC1905_EEPROM_LOCKED;
    }

    if (isBusy)
    {
      cmd_buf[1] = statusRegister;

      // milans 220809
      gpio_put(loadenbSC1905pin(), 0);

      return ERROR_SC1905_EEPROM_BUSY;
    }

    // Write
    clearBuffer(out_buf0);
    out_buf0[0] = 0x06; // WREN command to enable write operations to EEPROM

    cs_select(PERIPH_SC1905);
    spi_write_read_blocking(SPIMASTER, out_buf0, in_buf0, 1);
    cs_deselect(PERIPH_SC1905);
    sleep_ms(10);

    clearBuffer(out_buf0);
    out_buf0[0] = 0x02;
    out_buf0[1] = cmd_buf[2]; // Address
    out_buf0[2] = cmd_buf[3];
    out_buf0[3] = cmd_buf[5]; // Value
    out_buf0[4] = cmd_buf[6];

    uint8_t bytesNo = cmd_buf[4];

    cs_select(PERIPH_SC1905);
    spi_write_read_blocking(SPIMASTER, out_buf0, in_buf0, 3 + bytesNo);
    cs_deselect(PERIPH_SC1905);
    sleep_ms(10);

    /************************ EEPROM Checksum ************************/
    // Calculate checksum
    uint8_t checksum;
    int int_checksum = original_checksum;

    int_checksum += ((256 - original_values[0]) + cmd_buf[5]);
    if (bytesNo == 2)
      int_checksum += ((256 - original_values[1]) + cmd_buf[6]);

    checksum = int_checksum % 256;

    // Write checksum
    clearBuffer(out_buf0);
    out_buf0[0] = 0x06; // WREN command to enable write operations to EEPROM
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
void loop()
{
  if (Serial.available())
  {

    Serial.readBytes(activeBuffer, 1);
    if (activeBuffer[0] == CMD_LMS8FE_HELLO)
    {
      while (Serial.read() >= 0)
      {
      } // flush the receive buffer
      Serial.write((byte)CMD_LMS8FE_HELLO);
      //      setDiodeState(0);
      delay(100);
    }
    else
    {
      uint8_t *tx_buf;
      unsigned char command;
      command = activeBuffer[0];

      if (command >= LMS8001_CMD_MASK)
      {
        //        periphID = PERIPH_LMS8001_1; // Implement possibility to choose PERIPH_LMS8001_1
        cmd_errors = 0;
        activeBufferSize = BUFFER_SIZE_LMS8001;
        tx_buf = activeBufferLMS8001tx;
        LMS_Ctrl_Packet_Tx->Header.Command = LMS_Ctrl_Packet_Rx->Header.Command;
        LMS_Ctrl_Packet_Tx->Header.Data_blocks = LMS_Ctrl_Packet_Rx->Header.Data_blocks;
        LMS_Ctrl_Packet_Tx->Header.Status = STATUS_BUSY_CMD;
      }
      else
      {
        activeBufferSize = BUFFER_SIZE;
        tx_buf = activeBuffer;
      }

      wait_for_bytes(activeBufferSize - 1, 1000);
      Serial.readBytes(activeBuffer + 1, activeBufferSize - 1);
      activeBuffer[0] = doCommand(activeBuffer);
      //      activeBuffer[0] = command;

      //      Serial.write(activeBuffer,activeBufferSize);
      Serial.write(tx_buf, activeBufferSize);
    }
  }

   // B.J.
  if (FlagX == 1)
  {
    // interrupt on CSN happened, receive the 16-bit data from SPI
    FlagX = 0;
    MyFunction();
  }

  // B.J.:
  if (rdPtr != wrPtr)
  { // for debugging, does not happen in normal operation
    X10 = 0;
    X1 = 0;
    ConvertToAscii(RDbyteX[rdPtr], &X10, &X1);
    Serial.write(X10);
    Serial.write(X1);
    if (rdPtr < 127)
      rdPtr++;
    else
      rdPtr = 0;
    ConvertToAscii(RDbyteX[rdPtr], &X10, &X1);
    Serial.write(X10);
    Serial.write(X1);
    if (rdPtr < 127)
      rdPtr++;
    else
      rdPtr = 0;
    Serial.write('\n');
  }

  if (RegLMS8FE[0] == 1)
  { // flag set?

    RegLMS8FE[1] = 0x00;
    if (BuffLMS8FE[0] == CMD_LMS8FE_HELLO)
    {
      // BuffLMS8FE[0] = CMD_LMS8FE_HELLO; // not change
      RegLMS8FE[1] = 1; // packet length in bytes = 1
      //delay(100);
    }
    else
    {
      uint8_t command = 0x00;
      uint8_t m_bLMS8001 = 0x00;
      command = BuffLMS8FE[0];

      for (int i = 0; i< BUFFER_SIZE_LMS8001; i++)
           activeBuffer[i] = BuffLMS8FE[i];

      if (command >= LMS8001_CMD_MASK)
      {
        // periphID = PERIPH_LMS8001_1; // Implement possibility to choose PERIPH_LMS8001_1
        cmd_errors = 0; // ???
        // activeBufferSize = BUFFER_SIZE_LMS8001;
        // tx_buf = BuffLMS8FE;
        m_bLMS8001 = 0x01;      
        activeBufferSize = BUFFER_SIZE_LMS8001;
        RegLMS8FE[1] = BUFFER_SIZE_LMS8001; // packet length in bytes = 64
        LMS_Ctrl_Packet_Tx->Header.Command = LMS_Ctrl_Packet_Rx->Header.Command;
        LMS_Ctrl_Packet_Tx->Header.Data_blocks = LMS_Ctrl_Packet_Rx->Header.Data_blocks;
        LMS_Ctrl_Packet_Tx->Header.Status = STATUS_BUSY_CMD;
      }
      else
      {
        // activeBufferSize = BUFFER_SIZE;
        // tx_buf = BuffLMS8FE;
        activeBufferSize = BUFFER_SIZE;
        RegLMS8FE[1] = BUFFER_SIZE; // packet length in bytes = 16
      }
      activeBuffer[0] = doCommand(activeBuffer);

      // for transmit
      if (m_bLMS8001 == 0x01) {
        for (int i = 0; i< BUFFER_SIZE_LMS8001; i++)
            BuffLMS8FE[i] = activeBufferLMS8001tx[i];
      }
      else  {
        for (int i = 0; i< BUFFER_SIZE_LMS8001; i++)
            BuffLMS8FE[i] = activeBuffer[i];
      }
    }
    //RegLMS8FE[0] = 0; // not in progress now, clear flag
    RegLMS8FE[0] = 0xAA; // not in progress now, clear flag
    // start of data packet, required for synchronization
  }
}
// B.J.: for debugging, not happen in normal operation
void ConvertToAscii(uint8_t ch, uint8_t *pX10, uint8_t *pX1)
{

  uint8_t X10, X1 = 0;

  X10 = ((ch & 0xF0) >> 4);
  X1 = (ch & 0x0F);

  if (X10 > 9)
    X10 = X10 + 0x37; // A-F
  else
    X10 = X10 + 0x30; // 0-9

  if (X1 > 9)
    X1 = X1 + 0x37;
  else
    X1 = X1 + 0x30;

  *pX10 = X10;
  *pX1 = X1;
}

/*************************************************************************/
/************************** D O   C O M M A N D **************************/
/*************************************************************************/

int doCommand(uint8_t *cmd_buf)
{

  int result = COMPLETED;

  switch (cmd_buf[0])
  {

  case CMD_LMS8FE_GET_INFO:
  {
    clearBuffer(cmd_buf);
    //        cmd_buf[1] = 0x01; // FW_VER
    cmd_buf[1] = 0x02; // FW_VER
    cmd_buf[2] = 0x01; // HW_VER
    cmd_buf[3] = 1;    // Status
    cmd_buf[4] = 1;    // Status
    break;
  }

    //    case CMD_LMS8FE_DIODE: {
    //        setDiodeState(cmd_buf[1]);
    //        break;
    //      }

  // milans 220714
  case CMD_LMS8FE_RESET:
  {
    //        setDiodeState(cmd_buf[1]);
    //        clearBuffer();
    //        memset(activeState, 0, sizeof(activeState[0])*CHAIN_SIZE);
    //        shiftData(activeState, activeState);  // Shift Chain Data
    resetState();
    break;
  }
    // milans 221128
  case CMD_LMS8FE_LMS8_ENABLE:
  {
    uint8_t val = cmd_buf[1];
    //        setChainBit(LMS8001_1_RESETn_BYTE, LMS8001_1_RESETn_BIT, val, activeState, nextState);
    //        setChainBit(LMS8001_2_RESETn_BYTE, LMS8001_2_RESETn_BIT, val, nextState, nextState);
    //        setChainBit(LMS8001_1_RESETn_BYTE, LMS8001_1_RESETn_BIT, 0, activeState, nextState);
    //        setState(nextState);
    //        setChainBit(LMS8001_2_RESETn_BYTE, LMS8001_2_RESETn_BIT, 1, nextState, nextState);
    //        setChainBit(LMS8001_2_RESETn_BYTE, LMS8001_2_RESETn_BIT, 1, activeState, nextState);
    //        setState(nextState);

    setChainBit(LMS8001_1_RESETn_BYTE, LMS8001_1_RESETn_BIT, val, activeState, nextState);
    setChainBit(LMS8001_2_RESETn_BYTE, LMS8001_2_RESETn_BIT, val, nextState, nextState);
    setState(nextState);

    break;
  }
    // milans 221130
  case CMD_LMS8FE_SELECT_CHANNEL:
  {
    uint8_t val = cmd_buf[1];
    setChainBit(MISC_BYTE, MISC_CHANNEL_BIT, val, activeState, nextState);
    setState(nextState);
    break;
  }

    /*
      case CMD_LMS8FE_DIODESPI: {
          setDiodeState(1);
          delay(100);
          setDiodeState(0);
          delay(100);
          setDiodeState(1);
          delay(100);
          setDiodeState(0);

          out_buf0[0] = CMD_LMS8FE_DIODESPI;
          out_buf0[1] = cmd_buf[1];

          // Write the output buffer to MOSI, and at the same time read from MISO.
          spi_write_read_blocking(SPIMASTER, out_buf0, in_buf0, BUFFER_SIZE);

          break;
        }
  */
  case CMD_LMS8FE_SET_CONFIG_FULL:
  {
    //        clearBuffer();
    //        shiftData(cmd_buf + 1, activeState);  // Shift Chain Data
    setState(cmd_buf + 1);
    //        memcpy(activeState, cmd_buf + 1, sizeof(activeState[0])*CHAIN_SIZE);
    //        activeState[0] = cmd_buf[1];

    //        setupMCU(activeBuffer[CHAIN_SIZE + 1], activeState);  // Setup control signals directly from MCU
    //        setupMCU(cmd_buf[MCU_BYTE], activeState);  // Setup control signals directly from MCU
    //        setupMCU(cmd_buf[MCU_BYTE]);  // Setup control signals directly from MCU
    break;
  }

  case CMD_LMS8FE_GET_CONFIG_FULL:
  {
    clearBuffer(cmd_buf);
    memcpy(cmd_buf + 1, activeState, sizeof(activeState[0]) * STATE_SIZE);
    //        cmd_buf[1] = 0x89;
    break;
  }

  case CMD_SC1905_SPI_SPECIAL_COMMAND:
  {
    //      setDiodeState(1);
    //      delay(100);
    //      setDiodeState(0);

    uint8_t mrb[4];
    uint8_t mrb_rcv[4];

    uint8_t bytesCode = 0x00;

    mrb[0] = cmd_buf[1];
    mrb[1] = cmd_buf[2];
    mrb[2] = cmd_buf[3];
    mrb[3] = cmd_buf[4];

    result = sc1905_message_protocol(mrb, mrb_rcv);

    if (result != COMPLETED)
      return result;

    cmd_buf[1] = mrb_rcv[0];
    cmd_buf[2] = mrb_rcv[1];
    cmd_buf[3] = mrb_rcv[2];
    cmd_buf[4] = mrb_rcv[3];

    break;
  }

  case CMD_SC1905_SPI_MESSAGE_MEMORY:
  {
    //      setDiodeState(1);
    //      delay(100);
    //      setDiodeState(0);

    result = COMPLETED;

    uint8_t isEEPROM = cmd_buf[7];

    if (isEEPROM == 1)
    {
      result = sc1905_EEPROM(cmd_buf);
      if (result != COMPLETED)
        return result;
      break;
    }

    uint8_t mrb[4];
    uint8_t mrb_rcv[4];

    uint8_t bytesCode = 0x00;

    if (cmd_buf[1] == 1)
    { // read
      bytesCode = 0x04;
      if (cmd_buf[4] == 2)
        bytesCode = 0x06;
    }
    else
    { // write
      bytesCode = 0x00;
      if (cmd_buf[4] == 2)
        bytesCode = 0x02;
    }

    mrb[0] = (bytesCode << 4) | cmd_buf[2];
    mrb[1] = cmd_buf[3];
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

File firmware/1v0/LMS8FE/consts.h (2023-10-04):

#define CHAIN_SIZE              6  // chain bytes
//#define STATE_SIZE              7  // board state bytes (chain bytes + MCU STATE byte)
#define STATE_SIZE              8  // board state bytes (chain bytes + MCU state byte + MISC byte)

#define BUFFER_SIZE             16  // communication buffer size 16 bytes
#define BUFFER_SIZE_MODE         2  // communication buffer size 2 bytes for CMD_MODE
#define BUFFER_SIZE_LMS8001     64  // communication buffer size 64 bytes for communication with LMS8001

//#define RESETN_SC1904_PIN       11  // RP2040 GPIO pin connected to SC1904 RESETN PIN - This is just for test, on the LMS8FE board it will be connected to a shift register in the daisy chain
//#define RESETN_LMS8001_PIN      10  // RP2040 GPIO pin connected to LMS8001 RESETN PIN - This is just for test, on the LMS8FE board it will be connected to a shift register in the daisy chain
// RP2040 GPIO pin connected to SC1904 LOADENB PIN - This is just for test, on the LMS8FE board, there is no direct connection.
// Spare MCU pins are connected to a header. SC1905 control pins are connected to another header. In the current version the only way
// to establish connection is to connect a wire between the appropriate pins of these headers.
//#define LOADENB_SC1904_PIN      10  // Change this!!!
//#define LOADENB_SC1904_1_PIN    13
//#define LOADENB_SC1904_2_PIN    23
#define LOADENB_SC1905_1_PIN    13
#define LOADENB_SC1905_2_PIN    23

#define LMS64C_CTRL_HEADER_SIZE  8

#define PERIPH_SC1905    0
#define PERIPH_LMS8001   1
#define PERIPH_ADF4002   2

//get info
#define FW_VER     1
#define DEV_TYPE  LMS_DEV_LMS8FE
#define LMS_PROTOCOL_VER 1
#define HW_VER    0
#define EXP_BOARD   EXP_BOARD_UNSUPPORTED
